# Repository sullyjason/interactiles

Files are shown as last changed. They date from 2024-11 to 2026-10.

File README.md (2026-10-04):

# Interactiles

[Portfolio Link](https://showspace.so/p/9350)

## Idea

Developing an interactive grid of buttons that light up and change colors when pressed, designed to communicate, connect, and create art across distances. Each grid is connected via the internet to a corresponding grid, allowing users to share visual messages in real-time.

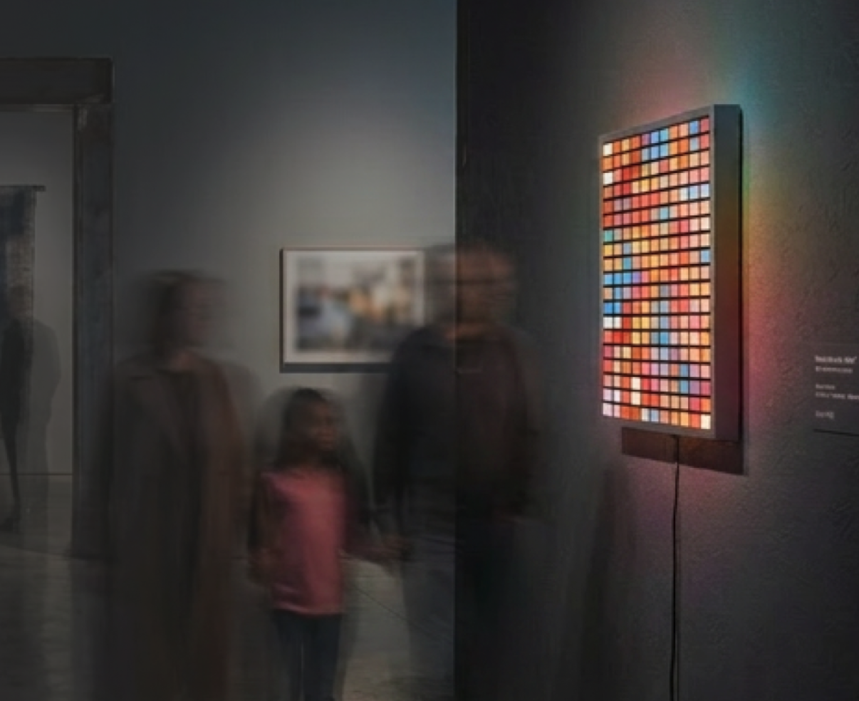
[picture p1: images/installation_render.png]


## Prototyping

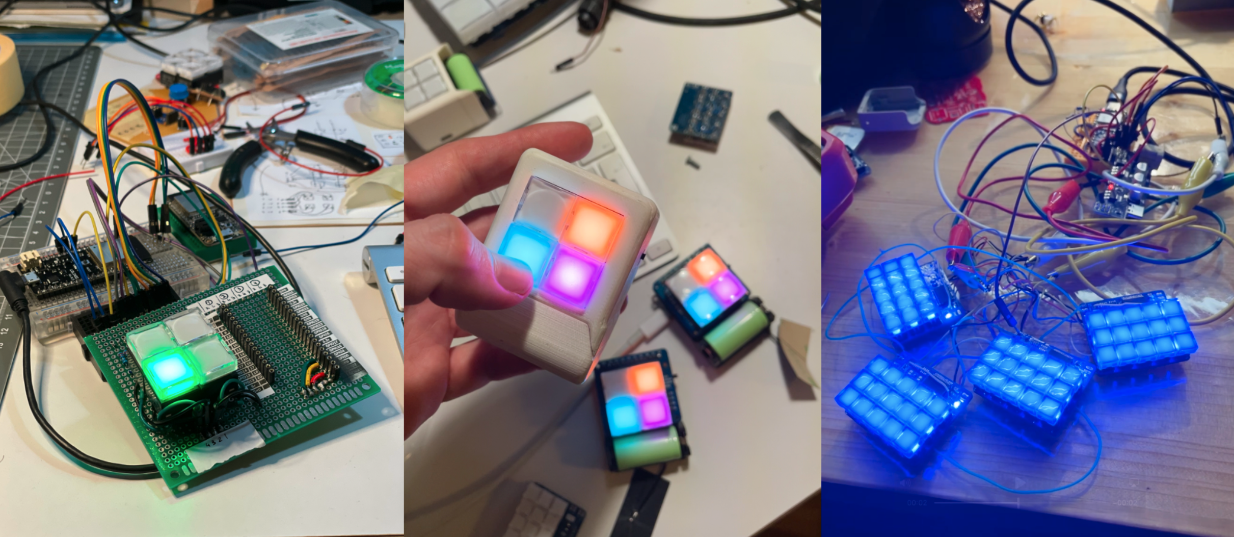
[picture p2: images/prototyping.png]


Until now, this project has served mostly as a platform for me to build on my coding and hardware skills. 

The current working prototype is a version with a 2x2 grid of RGB LED switches, connected to each other via an MQTT server.

The vision, of course, is a larger scale grid of clickable illuminated buttons. I am developing this with a modular approach, 4 tiles of 3x15 buttons controlled by a microcontroller that connects to the internet.

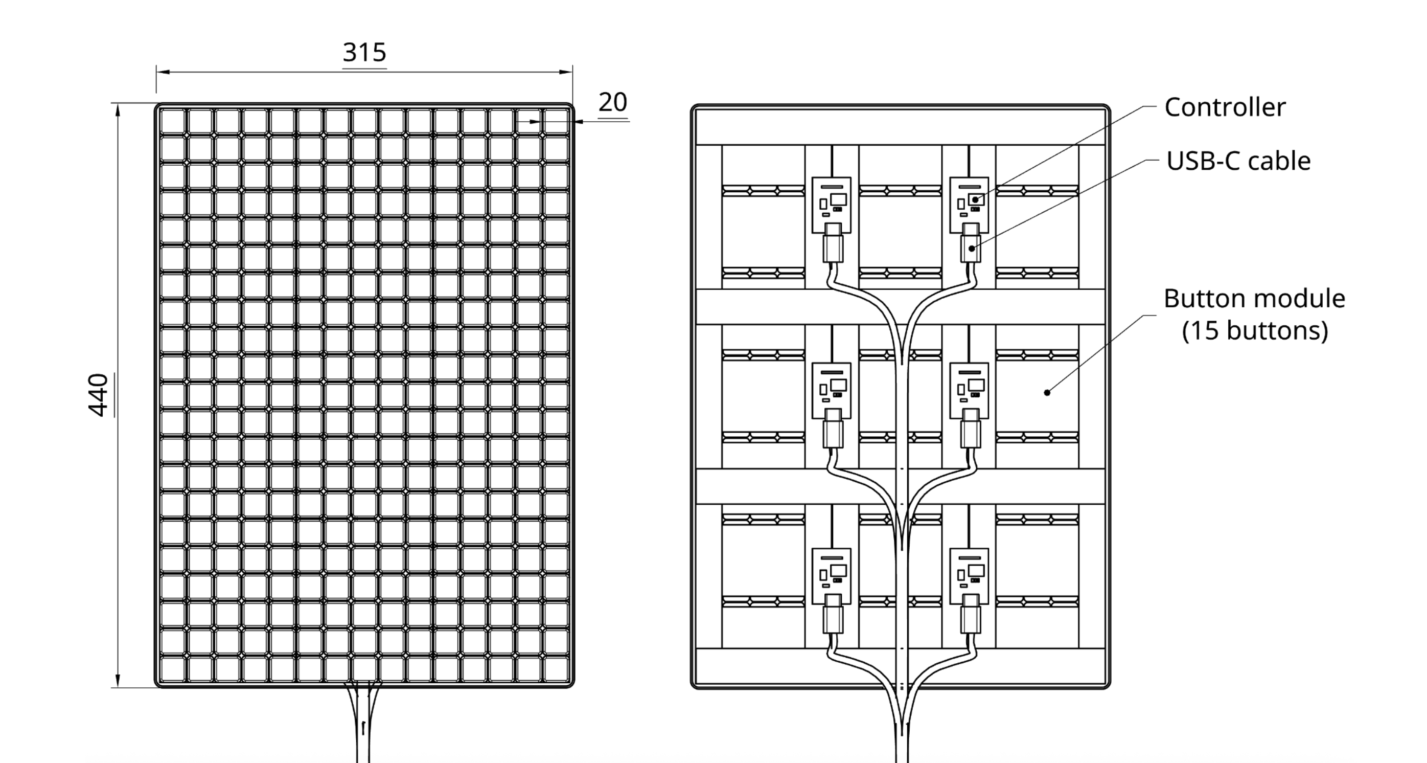
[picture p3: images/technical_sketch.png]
 

## To Do
- [x] Experiment with RGB Switches
- [x] Build hand-wired POC
- [x] Design PCB for 2x2 version
- [x] Assemble & test 2x2 version
- [x] Set up web server
- [x] Connect individual interactiles to web server
- [x] Web interface for monitoring
- [x] Large scale version module development (wip)
- [ ] Develop large scale version
- [ ] Design large scale modules
- [ ] Troubleshoot large scale modules
- [ ] Design miniature modules
- [ ] Enclosure for miniature modules
- [ ] Real world testing of 2x2 (in progress)

## Events

Exhibitions and real-world showings of Interactiles, each documented in its own folder under [`events/`](events/).

- [Zürich Decompression 2026](events/2026-decompression-zurich/) — two connected 5×3 grids in a fine-dining-inspired frame. Kraftwerk, Zürich, 9–11 October 2026.

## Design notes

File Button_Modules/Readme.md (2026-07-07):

# Button Modules

Addressable RGB switch panels in various sizes, built around 3×5 grids of NeoPixel-compatible switches. Button state is read via MCP23017 I2C I/O expanders. Switches are sourced from Lakeview Electronics in Shenzhen.

---

## Large Module

3×5 grid of PLB switches (~3×3 cm each). 15 switches routed to an FPC connector, with headers for the LED data line and screw terminals for 5V/GND.

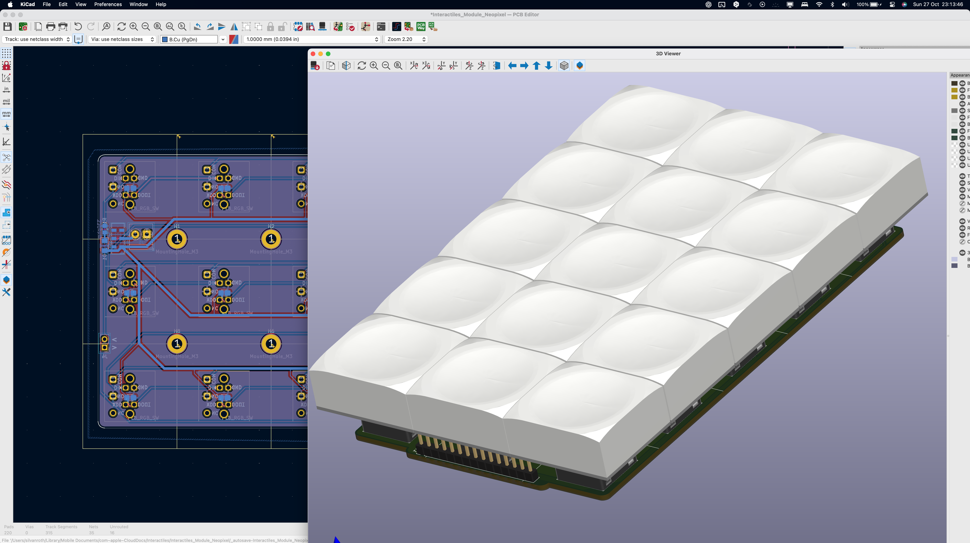
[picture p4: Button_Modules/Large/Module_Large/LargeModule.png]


→ [Large Module](Large/Module_Large/)

---

## Large Module I/O Expander

MCP23017-based expander board for the Large Module. Connects via FPC connector and reduces 15 switch lines to two I2C lines. I2C address set via DIP switch.

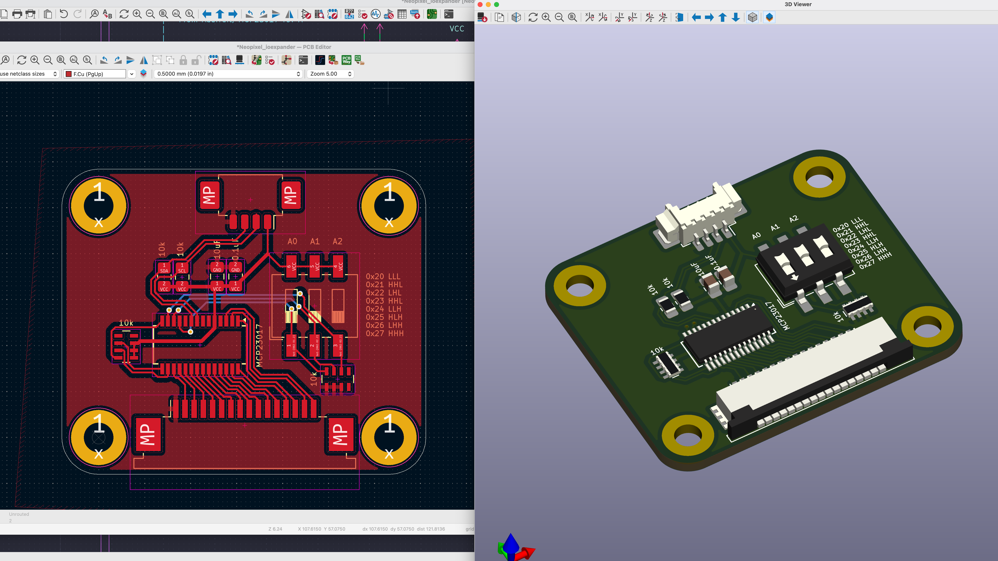
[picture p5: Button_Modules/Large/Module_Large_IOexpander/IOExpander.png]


→ [Module Large IOexpander](Large/Module_Large_IOexpander/)

---

## Mini Module

3×5 grid of TL1 switches (7.5mm² each). 4-layer board with MCP23017 mounted directly on the underside. Pinout is non-obvious due to space constraints — refer to schematic.

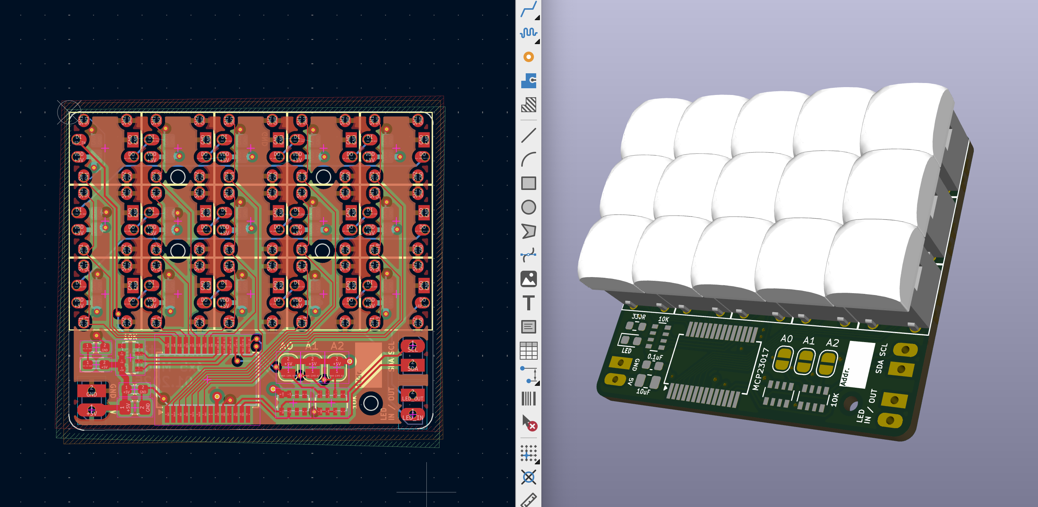
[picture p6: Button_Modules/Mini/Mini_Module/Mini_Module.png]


→ [Mini Module](Mini/Mini_Module/)

---

## Controllers

### 4x Mini Controller

Wireless ESP32 controller for up to 4 Mini Modules (60 pixels). Connects via I2C to MCP23017 expanders, drives one NeoPixel data line. Uses Li-ion batteries with BMS, battery charger etc.

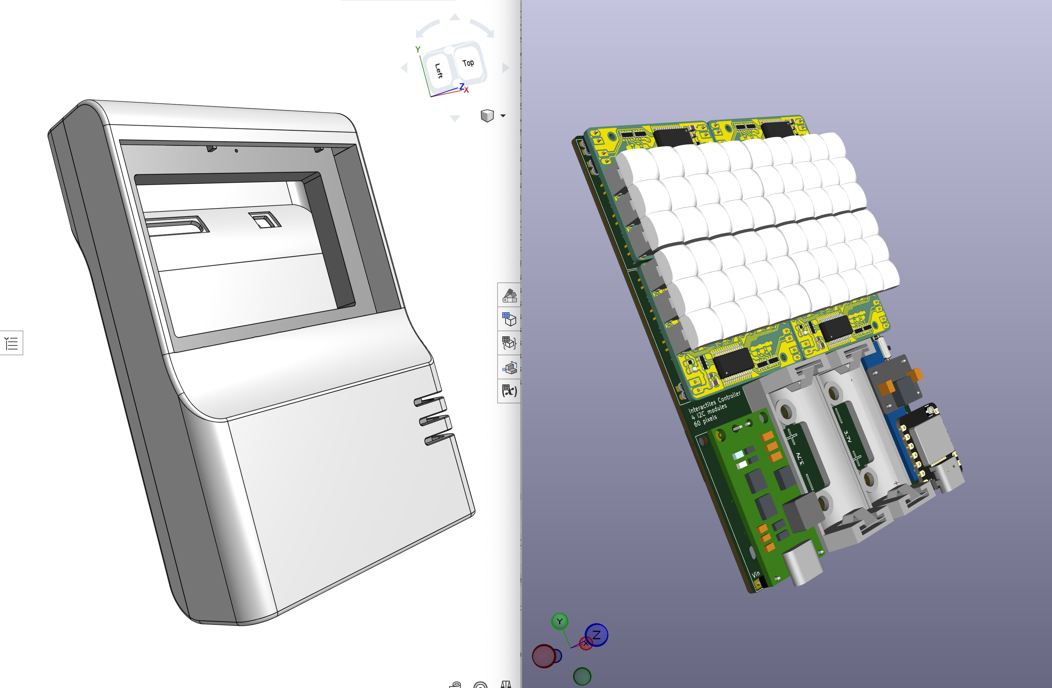
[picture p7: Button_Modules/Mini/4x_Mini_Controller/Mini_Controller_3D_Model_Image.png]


→ [4x Mini Controller](Mini/4x_Mini_Controller/)

### 4x Mini Controller Wired

Wired variant of the 4x Mini Controller, no batteries

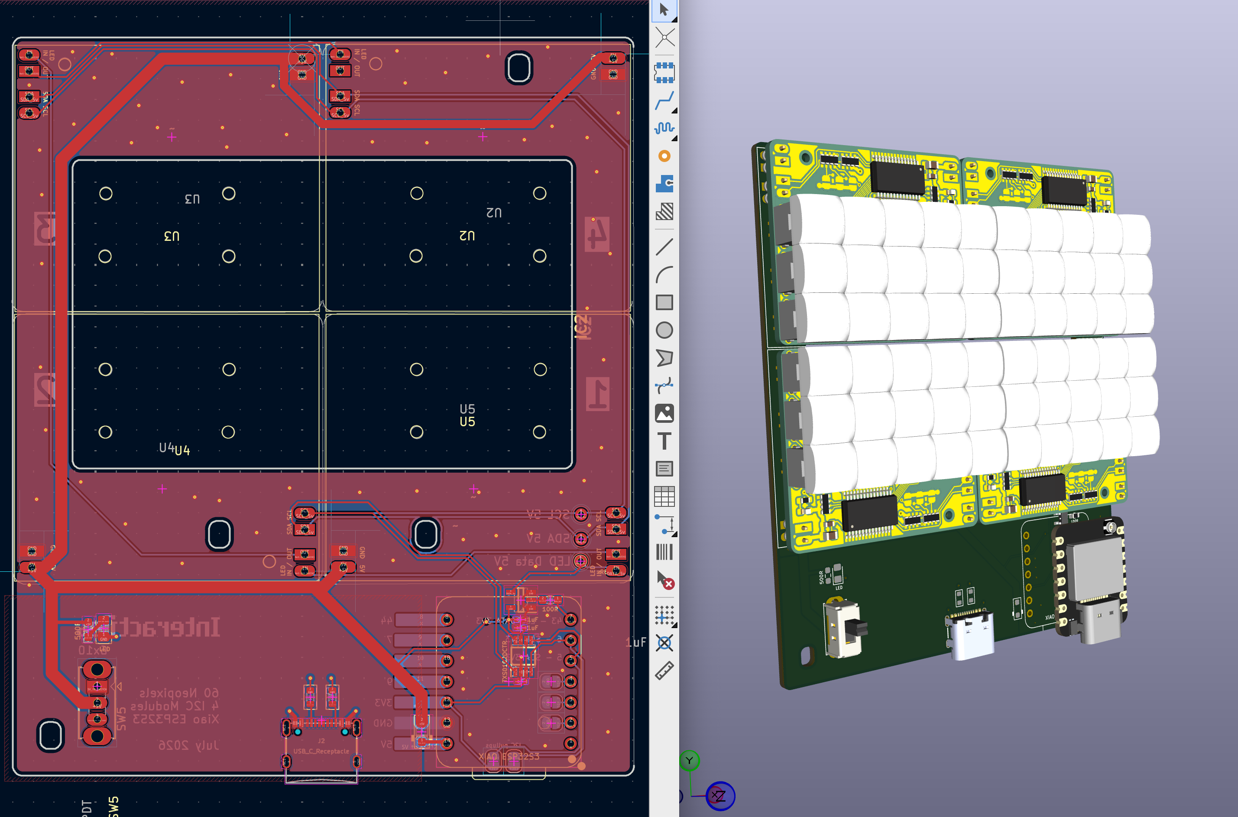
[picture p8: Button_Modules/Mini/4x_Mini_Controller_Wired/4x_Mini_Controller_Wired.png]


→ [4x Mini Controller Wired](Mini/4x_Mini_Controller_Wired/)

### Solo Mini Controller

Standalone controller for a single 3×5 Mini Module.

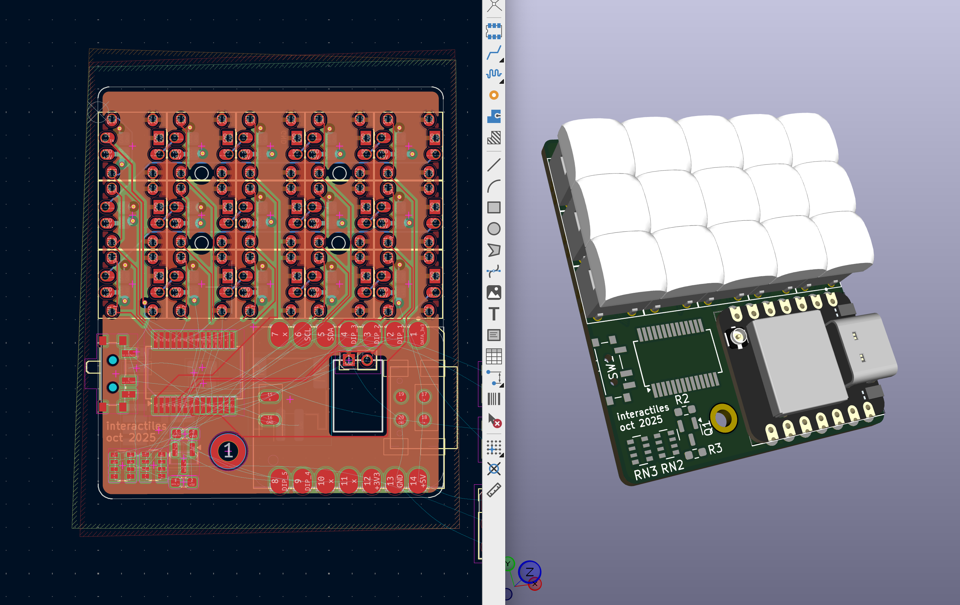
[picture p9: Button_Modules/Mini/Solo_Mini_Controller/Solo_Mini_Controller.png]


→ [Solo Mini Controller](Mini/Solo_Mini_Controller/)

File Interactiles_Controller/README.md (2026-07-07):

# Interactiles Controller PCB

Main controller board for the scaled-up Interactiles installation.

## Board

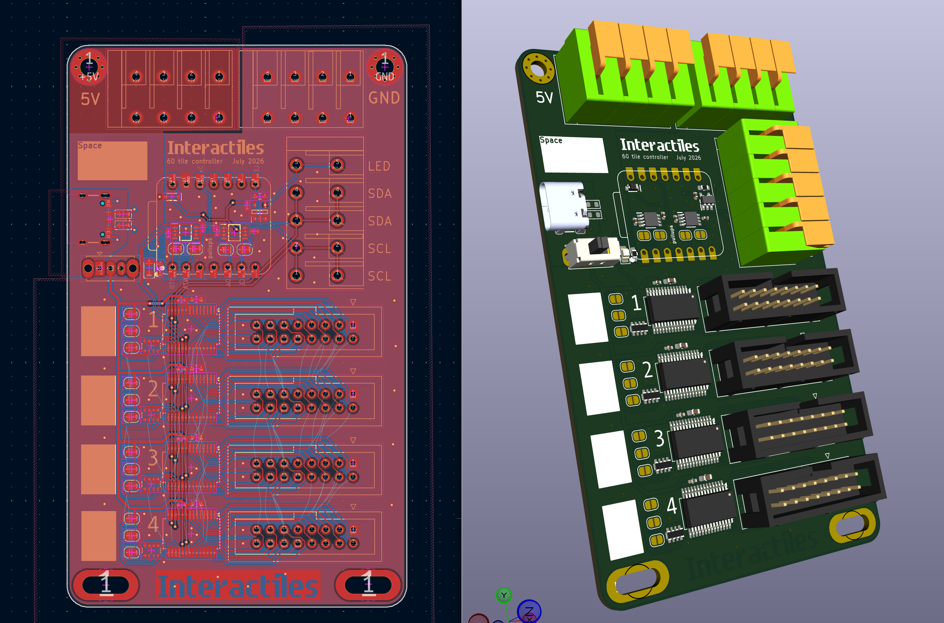
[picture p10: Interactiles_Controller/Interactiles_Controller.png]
Board


## Bodges

<!-- Document any wire fixes or component swaps here, with photos -->

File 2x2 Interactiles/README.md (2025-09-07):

readme.md

# 2x2 Interactile

Device with a 2x2 matrix of RGB Switches, controlled by an ESP32. The switches are arranged in a matrix configuration. WS2811 IC's control the RGB LEDs embedded in the switches, controlled using the Adafruit Neopixel library. 

The enclosure is 3D printed in PLA with an acrylic backplate, secured with M2 screws and a knurled nut to allow for easy battery switching. 

The battery is a CR123 sized 3.7 Li-Ion and provides the entire device with power. A polarity protection circuit protects the PCB but there is no charging circuit. 

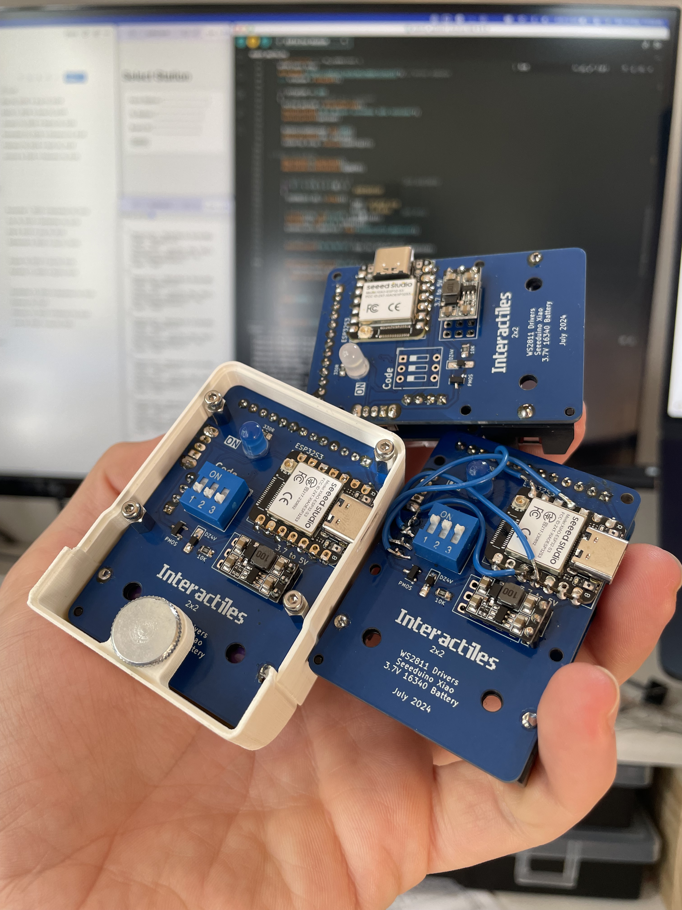
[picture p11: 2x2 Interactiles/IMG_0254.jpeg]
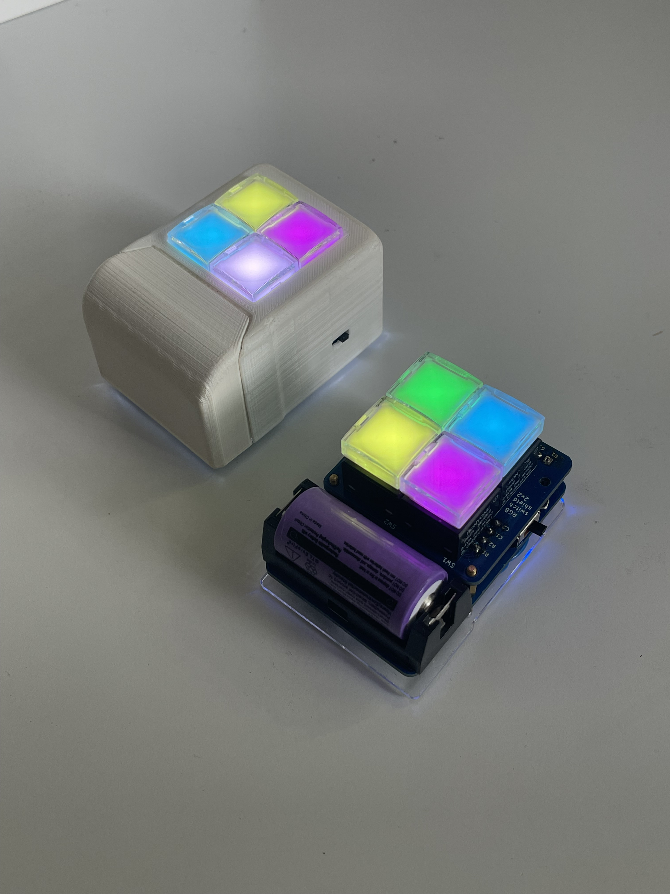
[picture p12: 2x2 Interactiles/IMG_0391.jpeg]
 

### Interfacing via MQTT

The current code in the folder named "MQTT" connects the interactiles to an MQTT server, where they publish and subscribe to channels that correspond to the individual pixels. 

The server is located at 
```c++
mqtt_server = "test.mosquitto.org";
mqtt_port = 1883;
base_topic = "interactiles/space1";
```

Configure Wifi settings here
```C++
// Wi-Fi credentials
const char* ssid = "SSID";
const char* password = "PASSWORD";
```

The channel structure is as follows:
interactiles/space[]/row/col/r,g,b

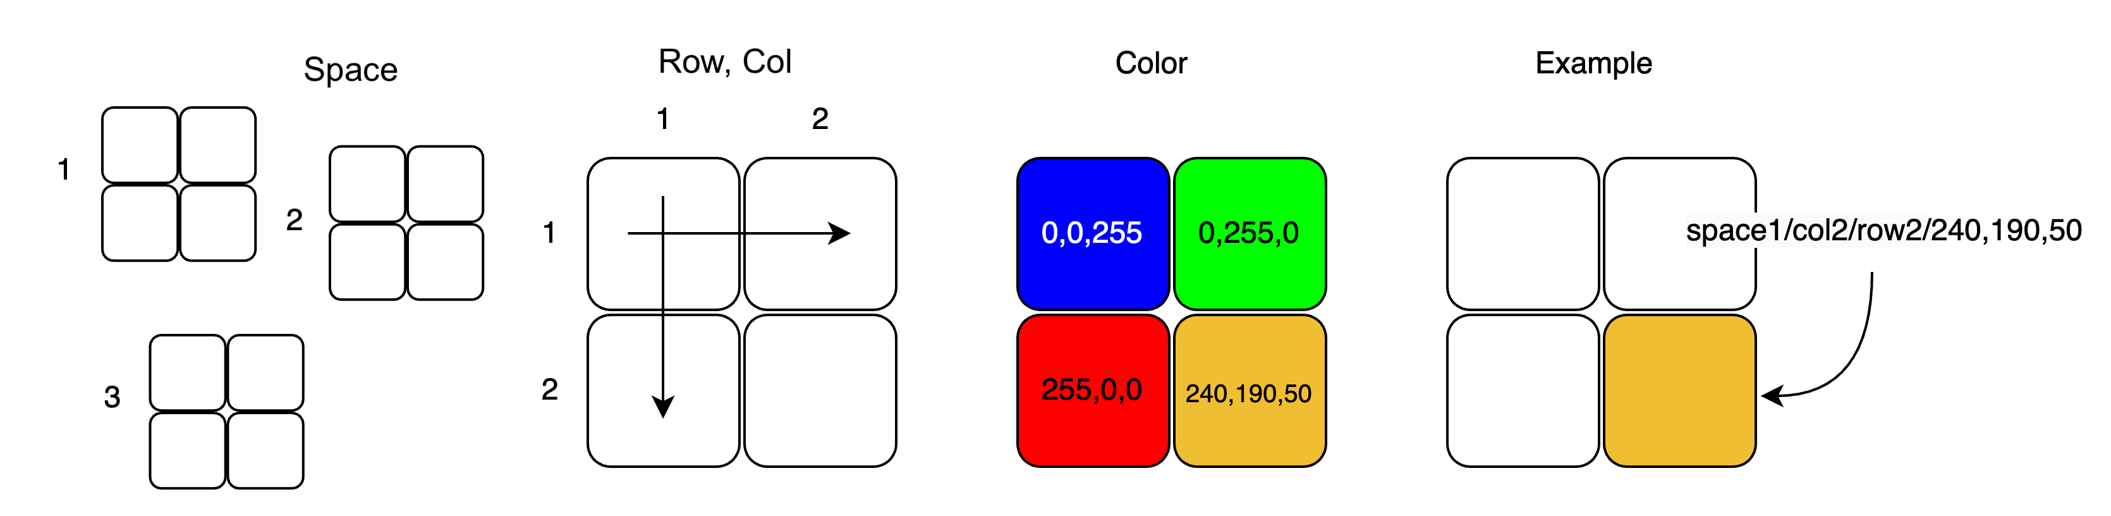
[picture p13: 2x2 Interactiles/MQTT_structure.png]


The space ID is currently hardcoded. In future versions it should be possible to set this via a DIP switch or similar.

row and column are matched to a specific RGB Switch as follows:
```c++
int mapToLedIndex(int row, int col) {
  if (row == 1 && col == 1) return 0;
  if (row == 1 && col == 2) return 2;
  if (row == 2 && col == 1) return 1;
  if (row == 2 && col == 2) return 3;
  return -1;
}
```

## Future changes
 
- Current version uses WS2811 LED drivers. Replace with intelligent RGB LED Switches
- Improve power management: Use xiao ESP32S3's onboard charging or redesign charging circuit. Alternatively, completely elminate wireless option
- Fix dip switch behavior
- Spaces architecture: The idea of spaces is that multiple devices can exist in the same space and be a part of the same image. Idea for naming: space1.1, space 1.2, etc.
- Hardcode meta data on each device and have the devices respond to each other accordingly
- MQTT or wifi connecting animation for improved usability
- consider creating a docking station
- Add wifi manager library

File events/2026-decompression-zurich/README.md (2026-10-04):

# Zürich Decompression 2026

**Status:** Upcoming — installation planned for 9–11 October 2026.

## The event

[Zürich Decompression 2026](https://zurich-decompression.web.app/) is a Burning Man decompression — a community gathering where burners process the burn through art, performances and workshops. It is volunteer-run, organised by the Zürich burner community, and held at **Kraftwerk, Zürich**.

This year's theme is *The Grand Hotel for Peculiar Burners*, where participants check in with a declared peculiarity that frames their experience. The guiding principle is that **the Hotel is built by whoever turns up** — everything is participant-created rather than organiser-programmed, and there are no spectators at a burn.

Art is submitted through the event's *Grand Hotel Dreams* category, with funding available for materials and transport.

| | |
|---|---|
| **Dates** | 9–11 October 2026 (Fri build night · Sat main event · Sun strike) |
| **Venue** | Kraftwerk, Zürich |
| **Website** | https://zurich-decompression.web.app/ |

## Our proposal

Submitted by **Silvan & Marco** to the Zürich Decompression art grant, September 2026.

The original Interactiles vision is a large-scale grid of several hundred illuminated buttons. For this event we proposed a **deliberately scaled-down version that stays close to the original concept**:

- **Two interactive 5×3 LED grids** — 15 physical buttons/LEDs per block, rather than the ~300 of the full concept.
- The two grids **communicate with each other**, preserving the core idea of connection across distance.
- To compensate for the small pixel count, the work leans on **presentation**: each grid is set in a generous, carefully built frame — in Marco's words, the way tiny portions of the best food are placed on giant plates at a fine dining restaurant.

This is a slight conceptual shift from the full installation, trading raw scale for framing and craft.

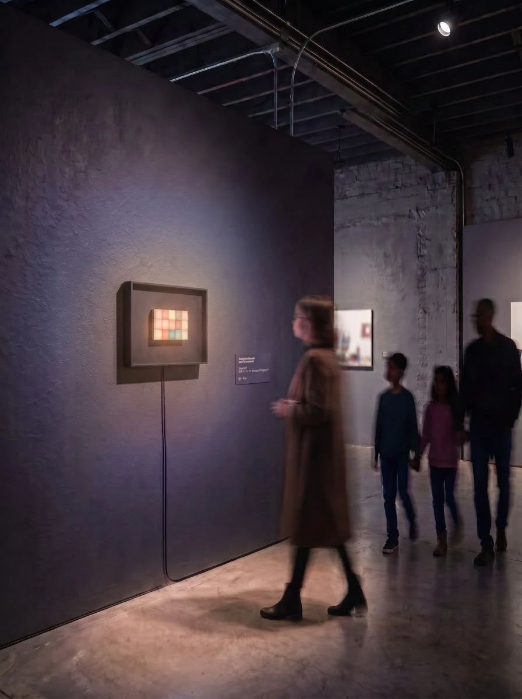
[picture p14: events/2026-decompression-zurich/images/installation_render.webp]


### Why this scope

The decisive factor was feasibility within the available timeframe. Marco got the **existing prototype working without significant hardware changes**, which meant the scaled-down version needs no complex component orders with long and risky delivery times. Effort goes into the two things that actually determine whether it works on the night:

1. A **sturdy frame**.
2. **Reliable software**.

Budget: **approximately CHF 500**, covering materials and transport.

### What we want out of it

A chance to test the concept in a **real event setting** and see how people actually interact with it. If it works, we plan to develop the larger installation together for next year's Decompression — with more time to build properly and significantly lower risk overall.

## What we're building

Both halves of the piece are built from boards that already exist in this repo — this is the point of the scaled-down scope, and the reason no new fabrication orders were needed.

### Boards

| Part | Board | Source |
|---|---|---|
| Brain | **Interactiles Controller** | [`Interactiles_Controller/`](../../Interactiles_Controller/) |
| Buttons | **2 × Large Module** | [`Button_Modules/Large/Module_Large/`](../../Button_Modules/Large/Module_Large/) |

**Controller** — built around a **XIAO ESP32-S3** for wifi and the MQTT link between the two grids. Button reads go through **4 × MCP23017** I²C port expanders (64 inputs available, of which this build uses 30), with TXS0102 level shifters on the I²C lines and an SN74AHCT1G125 buffer to lift the LED data line to 5 V. Modules connect over 2×16 IDC headers, with lever terminals for power distribution.

**Large Module** — a 3×5 grid of **PLB-N1PRGB-GTW-AI** illuminated RGB switches (15 per board, ~3×3 cm each), routed out to an FPC connector, with a header for LED data and a screw terminal for 5 V/GND.

Two modules give the **two 5×3 grids** of the proposal: 30 buttons total.

### Power

The controller is powered over **USB-C**, via a **5 m cable** into a **100 W charging brick**. Expected draw is **no more than ~15 W** — the load is dominated by the 30 RGB switches, and the controller itself is negligible beside them. The oversized brick is deliberate: the extra capacity is there for when the installation scales, not for this build.

### Open risks

- **LED data signal loss** on the Large Module is a known, still-unresolved issue (noted in that board's own README). Since reliable software and a working piece on the night are the whole point of this scope, this is the main technical risk to close before the event.
- **Power headroom is not currently accessible.** The controller's USB-C port is a plain 5 V sink — two 5.1 kΩ CC pulldowns, with no PD negotiation IC on the BOM — so it will only ever pull 5 V from the brick, capping it at roughly 15 W no matter how large the supply is. That is fine for this build, but the 100 W will not become available at scale without either a PD trigger/sink IC and a buck stage, or a separate 5 V supply.
- **5 m at 5 V is a long run.** Voltage drop across the cable scales with current, so a thin cable may brown the LEDs out at full brightness even though the brick is oversized. Worth using a cable with heavy (20 AWG or better) power conductors, and worth testing at full white before the event.

## Retrospective

*To be filled in after the event: what we built, what worked, what broke, how people interacted with it, and what we would change for the full-scale version.*

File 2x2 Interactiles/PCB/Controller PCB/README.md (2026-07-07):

# 2x2 Controller PCB

ESP32-based controller board for the 2x2 Interactile. Drives 4 WS2811 NeoPixels and reads a 2x2 keypad matrix.

## Schematic

<!-- Paste schematic screenshot here -->

## Board

<!-- Paste board layout screenshot here -->

## Bodges

<!-- Document any wire fixes or component swaps here, with photos -->

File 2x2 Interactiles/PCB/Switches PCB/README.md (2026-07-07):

# 2x2 Switches PCB

Breakout board for the Honyone RGB switches in the 2x2 Interactile. Routes switch contacts and WS2811 LED data lines to a connector.

## Schematic

<!-- Paste schematic screenshot here -->

## Board

<!-- Paste board layout screenshot here -->

## Bodges

<!-- Document any wire fixes or component swaps here, with photos -->

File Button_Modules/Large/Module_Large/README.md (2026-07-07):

# Large Module PCB

3×5 grid of PLB NeoPixel switches (~3×3 cm each). 15 switches routed to an FPC connector, with headers for LED data and screw terminals for 5V/GND.

## Board

Board

## Bodges

WIP - signal loss issues on LED Data line.

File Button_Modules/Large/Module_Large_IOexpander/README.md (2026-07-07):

# Module Large I/O Expander PCB

MCP23017-based I/O expander module. Reduces 15 individual switch lines to two I2C lines. I2C address set via DIP switch. Compatible with the Large Module via FPC connector.

## Schematic

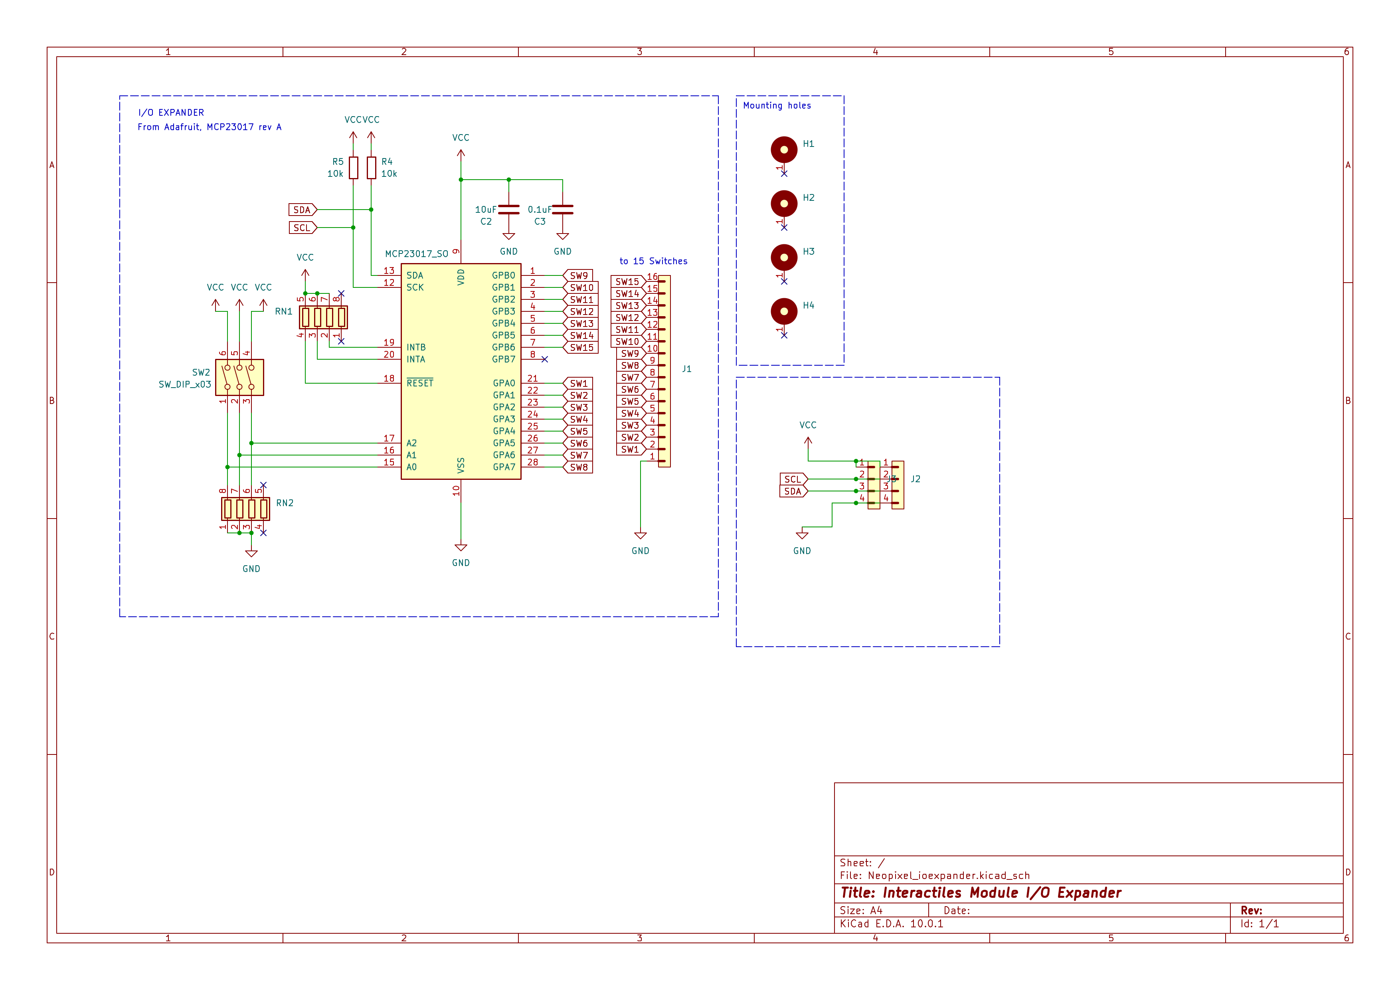
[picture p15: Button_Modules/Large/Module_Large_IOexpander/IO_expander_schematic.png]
Schematic


## Board

Board

## Bodges

i2c pullups are redundant if using several of these expanders, interrupt pins are tied high and not available for use

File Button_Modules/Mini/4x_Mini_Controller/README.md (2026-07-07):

# 4x Mini Controller PCB

ESP32 controller for a string of up to 8 3×5 NeoPixel modules. Interfaces: I2C (for MCP23017 expanders), NeoPixel data line, common ground. Includes USB-C and optional battery charging.

## Schematic

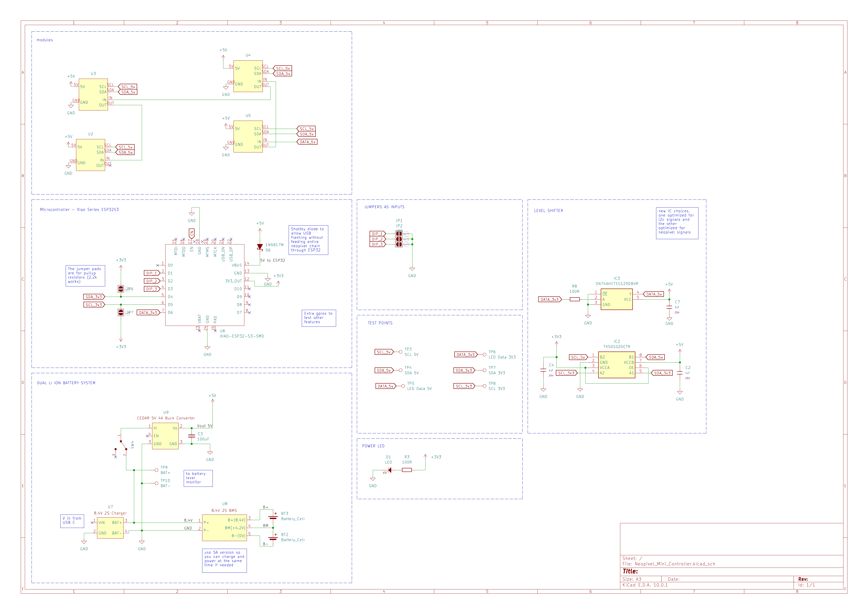
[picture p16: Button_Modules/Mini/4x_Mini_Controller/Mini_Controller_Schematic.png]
Schematic


## Board

Board

## Bodges

<!-- Document any wire fixes or component swaps here, with photos -->

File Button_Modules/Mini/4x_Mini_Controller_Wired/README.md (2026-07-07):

# 4x Mini Controller Wired PCB

Wired controller variant for a 4× 3×5 Mini Module Interactiles installation.

## Board

Board

## Bodges

<!-- Document any wire fixes or component swaps here, with photos -->

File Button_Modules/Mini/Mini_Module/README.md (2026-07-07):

# Mini Module PCB

3×5 grid of TL1 NeoPixel switches (7.5mm² each). 4-layer board with MCP23017 I/O expander mounted directly on the underside. Pinout is non-obvious due to space constraints — refer to schematic.

## Board

Board

## Bodges

<!-- Document any wire fixes or component swaps here, with photos -->

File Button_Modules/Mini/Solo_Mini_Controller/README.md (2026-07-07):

# Solo Mini Controller PCB

Standalone controller for a single 3×5 Mini Module.

## Board

Board

## Bodges

<!-- Document any wire fixes or component swaps here, with photos -->

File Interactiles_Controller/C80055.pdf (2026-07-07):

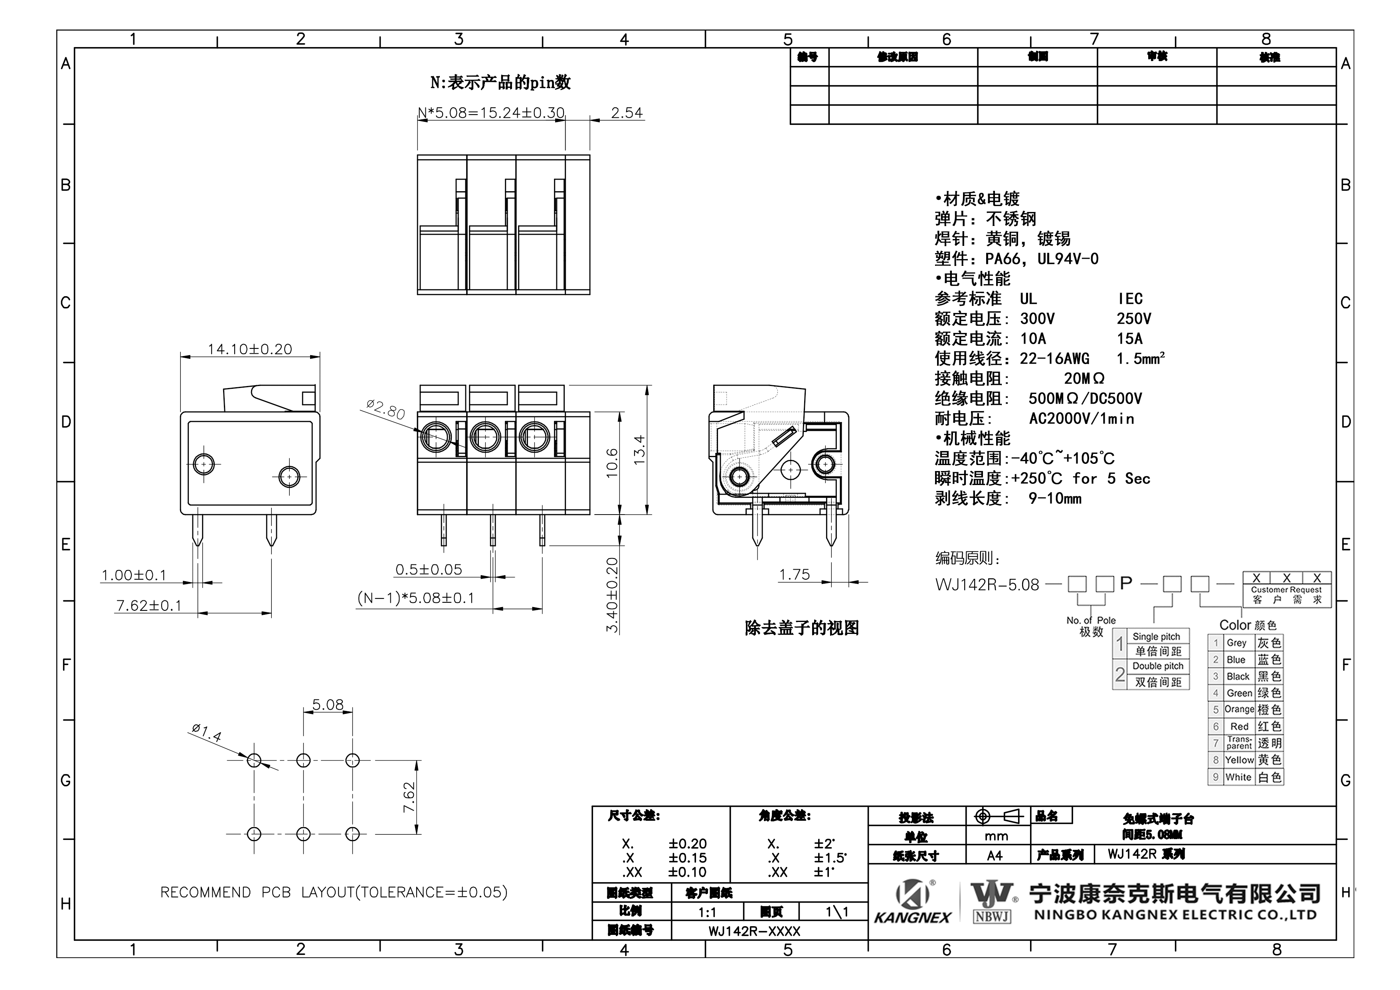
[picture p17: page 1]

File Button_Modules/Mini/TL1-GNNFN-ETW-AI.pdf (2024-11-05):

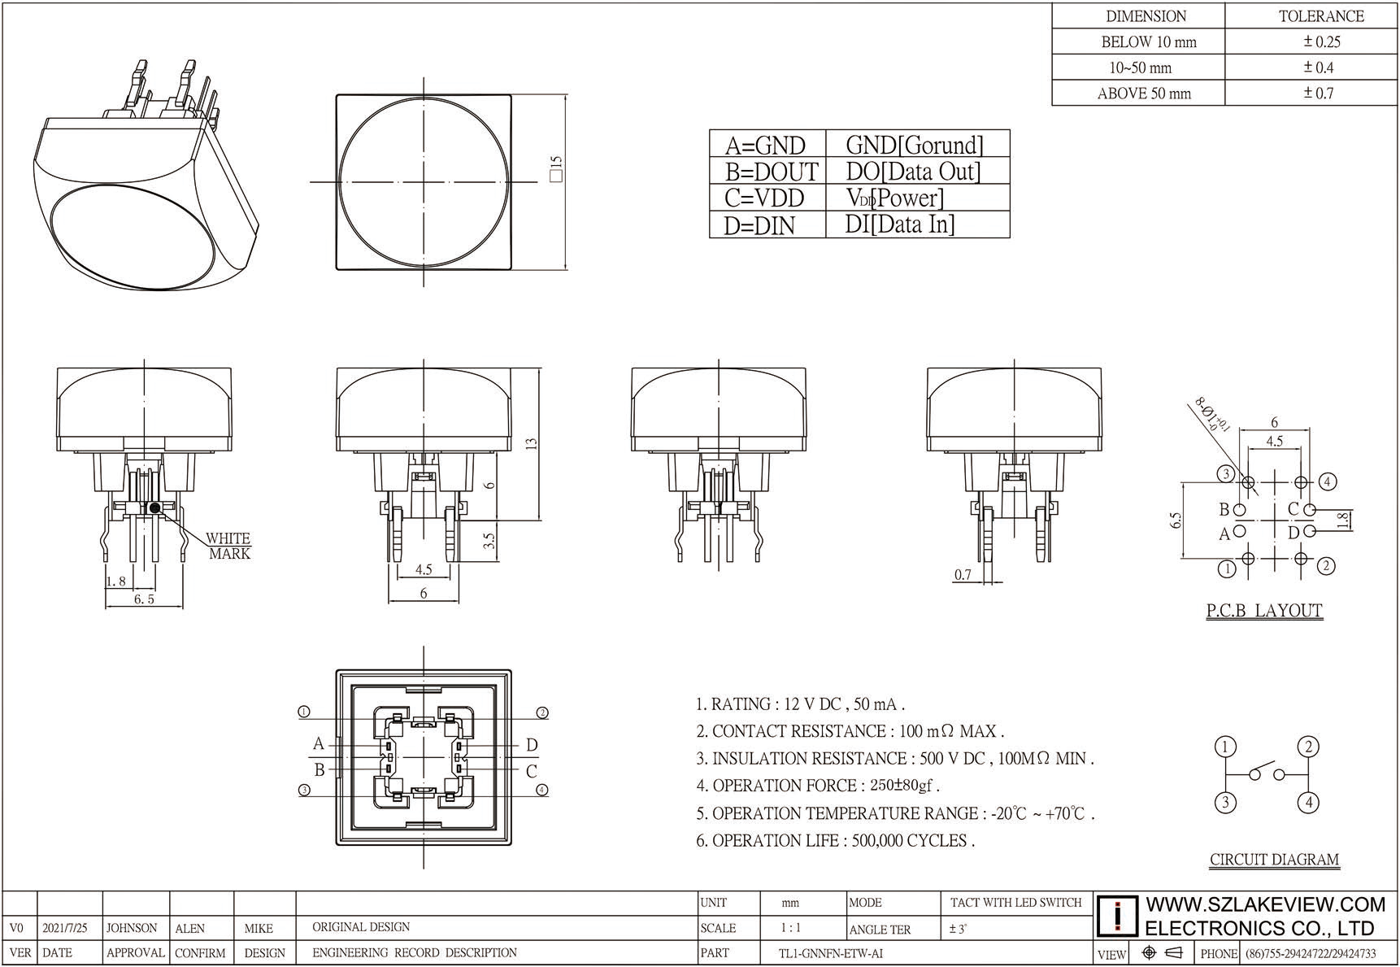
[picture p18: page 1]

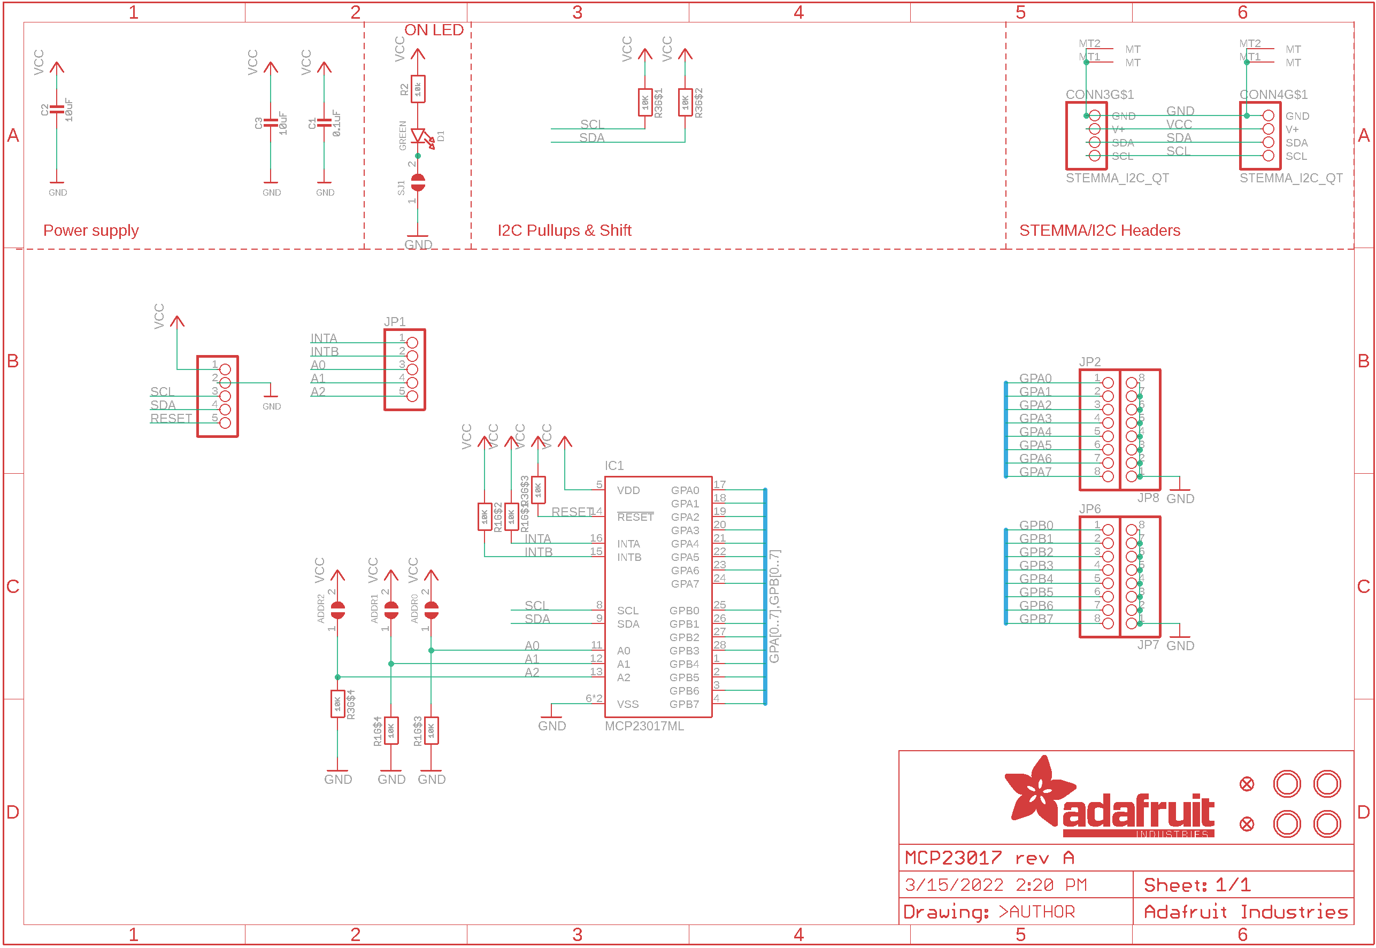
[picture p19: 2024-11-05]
Button_Modules/Components/Adafruit MCP23017 Schematic.png

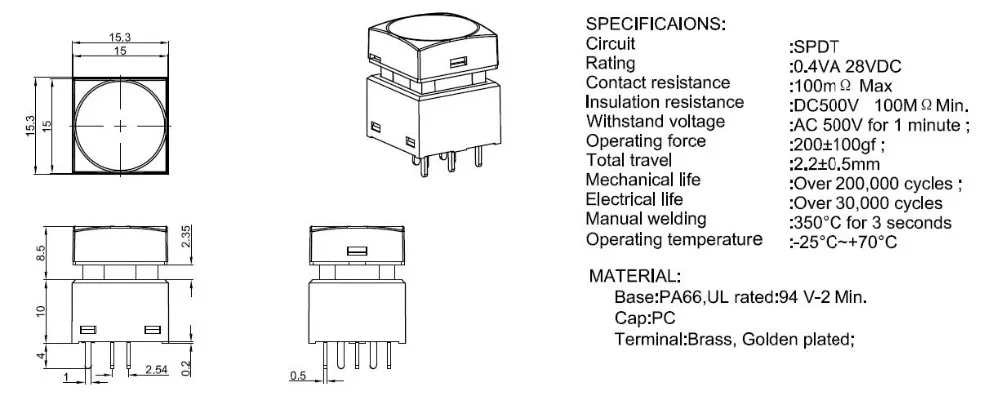
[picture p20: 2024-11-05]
2x2 Interactiles/PB26.jpg

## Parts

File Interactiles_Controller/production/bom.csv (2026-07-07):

Designator | Footprint | Quantity | Value | LCSC Part #
C2, C4, C6, C7, C8 | C_0402 | 5 | 1uF | C52923
C3_4, C3_3, C3_2, C3 | 0603 | 4 | 10uF
C5_4, C5_3, C5_2, C5 | 0402 | 4 | 0.1uF
D1 | 0805 | 1 | LED
D6 | SOD-323 | 1 | BAT60J
IC2, IC4 | TXS0102DCTR | 2 | TXS0102DCTR
IC3 | SN74AHCT1G125DBVR | 1 | SN74AHCT1G125DBVR
J2 | USB-C_16 | 1 | USB_C_Receptacle
J3, J4 | Lever_Terminal_1x04_WJ142R-5.08 | 2 | Screw_Terminal_01x04
J5 | Lever_Terminal_1x05_WJ142R-5.08 | 1 | Screw_Terminal_01x05
J7_4, J7_3, J7_2, J7 | IDC-Header_2x08_P2.54mm_Vertical | 4 | Conn_01x16
R1, R2 | 0603 | 2 | 5.1k
R3, R8 | 0603 | 2 | 100R
RN1_4, RN1_3, RN1_2, RN1 | R_Array_Convex_4x0603 | 4 | 10k
SW4 | SW_Slide_SPDT_Straight_CK_OS102011MS2Q | 1 | Slide_Switch_SPDT
U2_4, U2_3, U2_2, U2 | SSOP-28_5.3x10.2mm_P0.65mm | 4 | MCP23017_SS
U6 | XIAO-ESP32-S3-DIP | 1 | XIAO-ESP32-S3-SMD

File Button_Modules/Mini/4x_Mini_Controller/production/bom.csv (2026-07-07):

Designator | Footprint | Quantity | Value | LCSC Part #
BT2, BT3 | BHC-CR123A | 2 | Battery_Cell
C2, C4, C7 | C_0402 | 3 | 1uF | C52923
C3 | 1206 | 1 | 100uF
D1 | 0805 | 1 | LED
D6 | D_SOD-323_BigPads | 1 | 1N5817M
IC2 | TXS0102DCTR | 1 | TXS0102DCTR
IC3 | SN74AHCT1G125DBVR | 1 | SN74.
R3, R8 | 0603 | 2 | 100R
SW4 | SW_SPDT_PCM12 | 1 | Slide_Switch_SPDT
TP10 | TestPoint_THTPad_D1.5mm_Drill0.7mm | 1 | BAT-
TP3 | TestPoint_THTPad_D1.5mm_Drill0.7mm | 1 | SCL 5V
TP4 | TestPoint_THTPad_D1.5mm_Drill0.7mm | 1 | SDA 5V
TP5 | TestPoint_THTPad_D1.5mm_Drill0.7mm | 1 | LED Data 5V
TP9 | TestPoint_THTPad_D1.5mm_Drill0.7mm | 1 | BAT+
U2, U3, U4, U5 | Mini_Module | 4 | ~
U6 | XIAO-ESP32-S3-DIP | 1 | XIAO-ESP32-S3-SMD
U7 | 2S_Li_Ion_Charger | 1 | 8.4V 2S Charger
U8 | 8.4V_2S_BMS | 1 | 8.4V 2S BMS
U9 | CEDAR_5V_4A_Buck_Converter | 1 | 5V 4A Stepdown

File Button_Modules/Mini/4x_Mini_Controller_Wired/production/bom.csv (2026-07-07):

Designator | Footprint | Quantity | Value | LCSC Part #
C2, C4, C7 | C_0402 | 3 | 1uF | C52923
D1 | 0805 | 1 | LED
D6 | D_SOD-323_BigPads | 1 | 1N5817M
IC2 | TXS0102DCTR | 1 | TXS0102DCTR
IC3 | SN74AHCT1G125DBVR | 1 | SN74AHCT1G125DBVR
J2 | USB-C_16 | 1 | USB_C_Receptacle
R1, R2 | 0603 | 2 | 5.1k
R3 | 0603 | 1 | 500R
R8 | 0603 | 1 | 100R
SW5 | SW_Slide_SPDT_Straight_CK_OS102011MS2Q | 1 | Slide_Switch_SPDT
TP3 | TestPoint_THTPad_D1.5mm_Drill0.7mm | 1 | SCL 5V
TP4 | TestPoint_THTPad_D1.5mm_Drill0.7mm | 1 | SDA 5V
TP5 | TestPoint_THTPad_D1.5mm_Drill0.7mm | 1 | LED Data 5V
U2, U3, U4, U5 | Mini_Module | 4 | ~
U6 | XIAO-ESP32-S3-DIP | 1 | XIAO-ESP32-S3-SMD

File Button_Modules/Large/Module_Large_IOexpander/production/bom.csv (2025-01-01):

Designator | Footprint | Quantity | Value | LCSC Part #
0.1uF | 0805 | 1 | 0.1uF
10k_4, 10k_3 | R_Array_Concave_4x0603 | 2 | R_Pack04
10k_2, 10k | 0805 | 2 | 10k
10uF | 0805 | 1 | 10uF
H1, H2, H3, H4 | MountingHole_3.2mm_Pad | 4 | MountingHole_M3_3.2mm_Pad
J1 | TE_1-84952-6_1x16-1MP_P1.0mm_Horizontal | 1 | PINHD_1x16_Male
J2 | Molex_PicoBlade_53261-0471_1x04-1MP_P1.25mm_Horizontal | 1 | PINHD_1x4_Male
J3 | PinHeader_1x04_P2.54mm_Vertical | 1 | PINHD_1x4_Male
MCP23017 | SOIC-28W_7.5x17.9mm_P1.27mm | 1 | MCP23017_SO
SW2 | SW_DIP_SPSTx03_Slide_6.7x9.18mm_W8.61mm_P2.54mm_LowProfile | 1 | SW_DIP_x03

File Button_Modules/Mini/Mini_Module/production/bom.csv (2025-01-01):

Designator | Footprint | Quantity | Value | LCSC Part #
0.1uF | 0603 | 1 | 0.1uF
10uF | 0805 | 1 | 10uF
J1 | PinHeader_1x02_P2.00mm_Vertical | 1 | PINHD_1x2_Male
J2, J4 | PinHeader_1x02_P2.00mm_Vertical | 2 | PINHD_1x2_Female
LED | 0603 | 1 | LED
MCP23017 | SSOP-28_5.3x10.2mm_P0.65mm | 1 | MCP23017_SS
R1 | 0603 | 1 | 330R
RGB_SW1, RGB_SW10, RGB_SW11, RGB_SW12, RGB_SW13, RGB_SW14, RGB_SW15, RGB_SW2, RGB_SW3, RGB_SW4, RGB_SW5, RGB_SW6, RGB_SW7, RGB_SW8, RGB_SW9 | TL1_RBG_Adressable_1_mini | 15 | PLB_RGB_SW
RN1, RN2, RN3 | R_Array_Convex_4x0603 | 3 | R_Pack04

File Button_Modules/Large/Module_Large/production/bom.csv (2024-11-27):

Designator | Footprint | Quantity | Value | LCSC Part #
D1 | 1206 | 1 | LED
J1 | TerminalBlock_Phoenix_PT-1,5-2-3.5-H_1x02_P3.50mm_Horizontal | 1 | Screw_Terminal_2_P3.50mm
J2 | PinHeader_1x15_P2.54mm_Vertical | 1 | PINHD_1x15_Male
J3 | TE_1-84952-6_1x16-1MP_P1.0mm_Horizontal | 1 | PINHD_1x15_Male
J4 | PinSocket_1x02_P2.54mm_Vertical | 1 | PINHD_1x2_Female
R1 | 0805 | 1 | 330ohm
RGB_SW1, RGB_SW10, RGB_SW11, RGB_SW12, RGB_SW13, RGB_SW14, RGB_SW15, RGB_SW2, RGB_SW3, RGB_SW4, RGB_SW5, RGB_SW6, RGB_SW7, RGB_SW8, RGB_SW9 | PLB-N1PRGB-GTW-AI | 15 | PLB_RGB_SW
SW1 | SW_DPDT_CK_JS202011JCQN | 1 | SW_SPST

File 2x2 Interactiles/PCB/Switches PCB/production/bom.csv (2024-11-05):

Designator | Footprint | Quantity | Value | LCSC Part #
J1 | PinHeader_1x04_P2.54mm_Vertical | 1 | PINHD_1x4_Male
J2 | PinHeader_1x13_P2.54mm_Vertical | 1 | PINHD_1x13_Male
SW1 | Honyone Tactile Switch RGB | 1 | RGB_SW_1
SW2 | Honyone Tactile Switch RGB | 1 | RGB_SW_2
SW3 | Honyone Tactile Switch RGB | 1 | RGB_SW_3
SW4 | Honyone Tactile Switch RGB | 1 | RGB_SW_4

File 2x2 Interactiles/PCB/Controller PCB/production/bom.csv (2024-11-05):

Designator | Footprint | Quantity | Value | LCSC Part #
3.7V | BHC-CR123A | 1 | Battery 3.7V
C1, C2, C3, C4 | 0805 | 4 | 100nF_Ceramic
D1 | LED_D3.0mm | 1 | LED_3mm
D2 | 0805 | 1 | DZ4V
J1 | PinSocket_1x04_P2.54mm_Vertical | 1 | Switches
J2 | PinSocket_1x13_P2.54mm_Vertical | 1 | LEDs
J5 | PinSocket_1x03_P2.54mm_Vertical | 1 | 3.7 to 5V
PMOS | SOT-23 | 1 | AO3401A
R1, R6, R7, R8 | 0805 | 4 | 100R
R11 | 0805 | 1 | 330R
R2, R3, R4 | 0805 | 3 | 33R
R5, R9 | 0805 | 2 | 10k
SW1 | SW_Slide_SPDT_Angled_CK_OS102011MA1Q | 1 | SW_SPST
SW2 | SW_DIP_SPSTx03_Slide_9.78x9.8mm_W7.62mm_P2.54mm | 1 | SW_DIP_x03
U1 | Seeeduino XIAO-MOUDLE14P-2.54-21X17.8MM | 1 | SeeeduinoXIAO
U2, U3, U4, U5 | HSOP-8-1EP_3.9x4.9mm_P1.27mm_EP2.3x2.3mm | 4 | WS2811

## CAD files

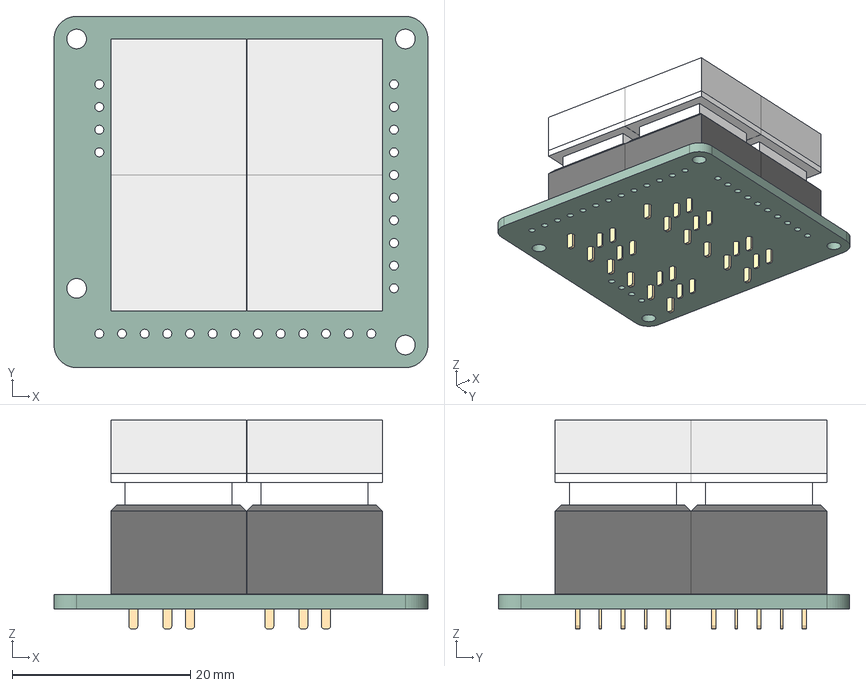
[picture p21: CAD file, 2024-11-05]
2x2 Interactiles/Enclosure/Honyone RGB Shield.step
41.9 x 39.4 x 23.4 mm
11ABBC06-2790-4AA7-BFDE-7ACAB21791F7 x 4
_autosave-Honyone RGB Shield_PCB

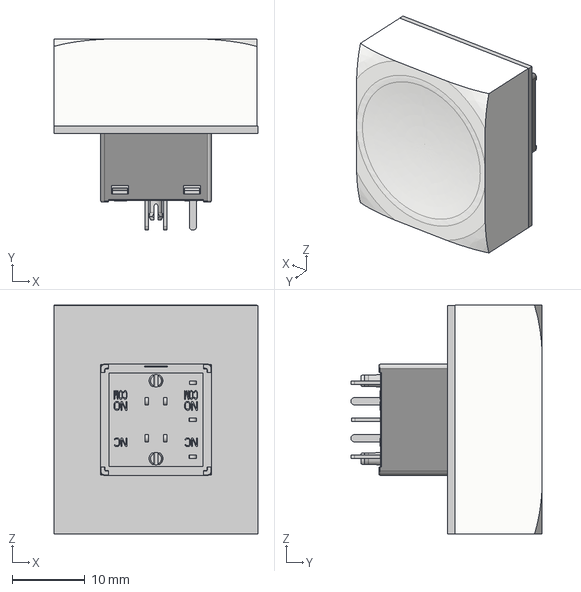
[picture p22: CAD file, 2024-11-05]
Button_Modules/Components/3D Files/PLB-N1PRGB-GTW-AI v2.step
28.0 x 26.3 x 31.5 mm

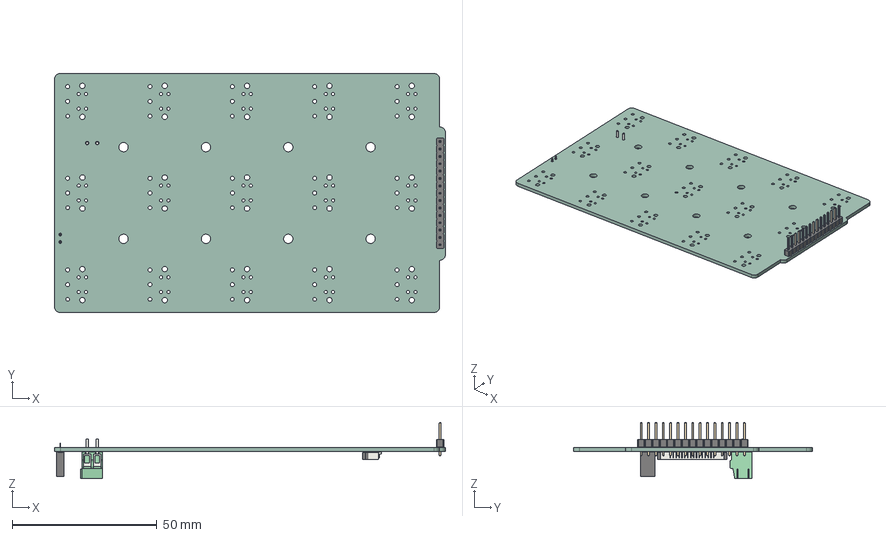
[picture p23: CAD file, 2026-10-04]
Button_Modules/Large/Module_Large/Neopixel_Mini_Controller_wired2.step
134.8 x 82.4 x 19.4 mm
PinHeader_1x15_P2.54mm_Vertical
PinSocket_1x02_P2.54mm_Vertical
R_0805_2012Metric
LED_1206_3216Metric
TerminalBlock_Phoenix_PT-1,5-2-3.5-H_1x02_P3.50mm_Horizontal
TE_1-84952-6_1x16-1MP_P1.0mm_Horizontal
Interactiles_Module_Neopixel_PCB

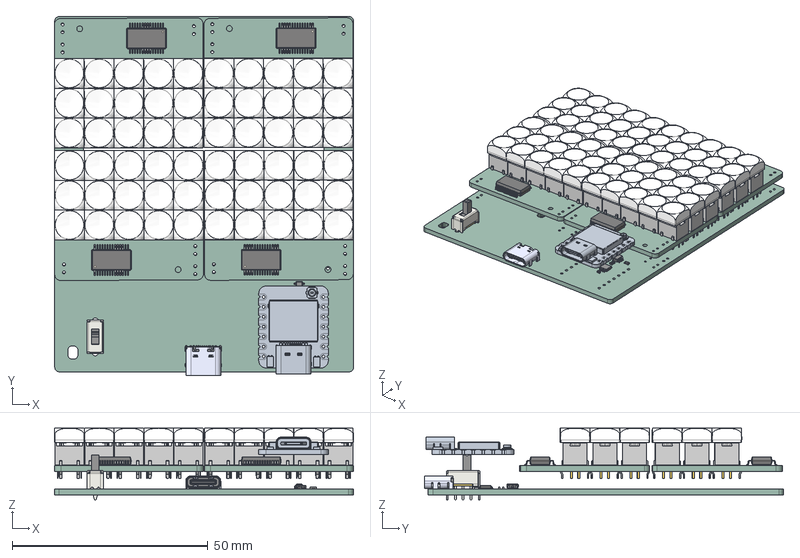
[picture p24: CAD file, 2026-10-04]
Button_Modules/Mini/4x_Mini_Controller_Wired/Neopixel_Mini_Controller_wired2.step
76.4 x 91.7 x 18.3 mm
C_0402 x 3
TL1-mini x 60
SSOP-28_5.3x10.2mm_P0.65mm x 4
Mini_Module_PCB x 4
BODY-SOT
LEAD-SOT x 5
LEAD-DUMMY
R_0603_1608Metric
BODY-SO
LEAD-SO x 8
PIN1-ID
Seeed_XIAO-ESP32S3
SW_Slide_SPDT_Straight_CK_OS102011MS2Q
USB4105GFA_USB4105GFA
4x_Mini_Controller_Wired_PCB

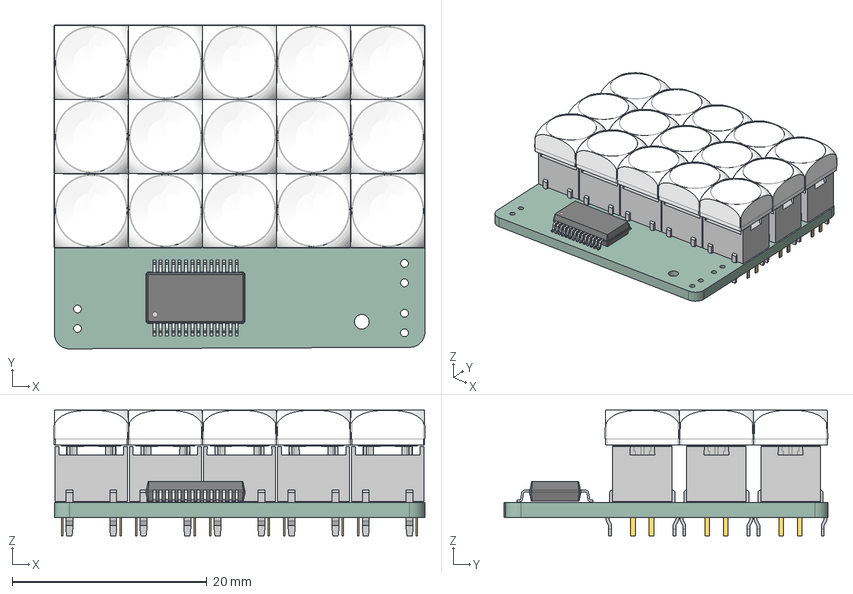
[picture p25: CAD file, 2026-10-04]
Button_Modules/Mini/Mini_Module/Neopixel_Mini_Controller.step
38.1 x 33.2 x 12.9 mm
TL1-mini x 15
SSOP-28_5.3x10.2mm_P0.65mm
Mini_Module_PCB

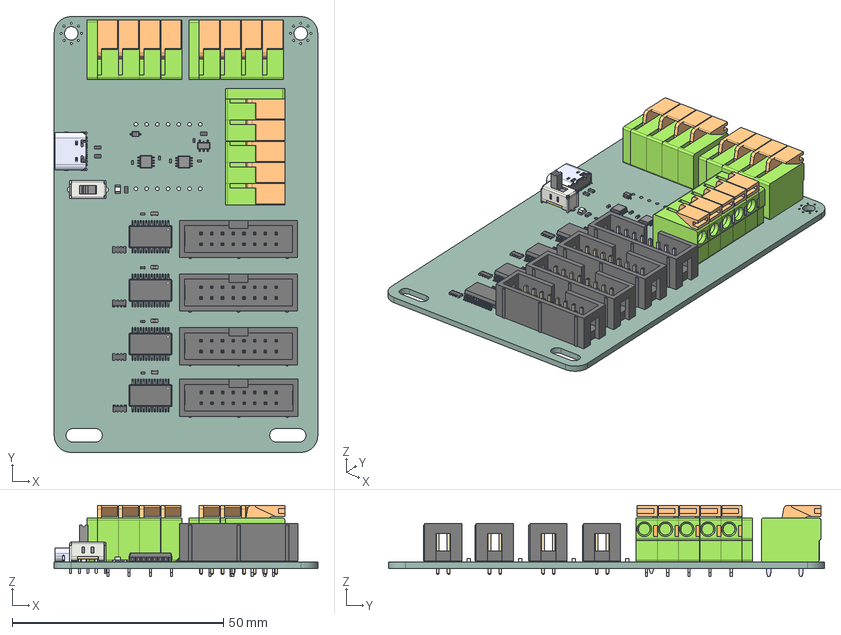
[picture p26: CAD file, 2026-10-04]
Interactiles_Controller/Interactiles_Controller.step
62.5 x 103.3 x 16.9 mm
C_0603_1608Metric x 4
R_Array_Convex_4x0603 x 4
R_0603_1608Metric x 4
C_0402 x 9
BODY-SO x 2
LEAD-SO x 16
PIN1-ID x 2
SW_Slide_SPDT_Straight_CK_OS102011MS2Q
LED_0805_2012Metric
SSOP-28_5.3x10.2mm_P0.65mm x 4
DG142R-2-5.08 x 16
D_SOD-323
BODY-SOT
LEAD-SOT x 5
LEAD-DUMMY
IDC-Header_2x08_P2.54mm_Vertical x 4
USB4105GFA_USB4105GFA
Interactiles_Controller_PCB

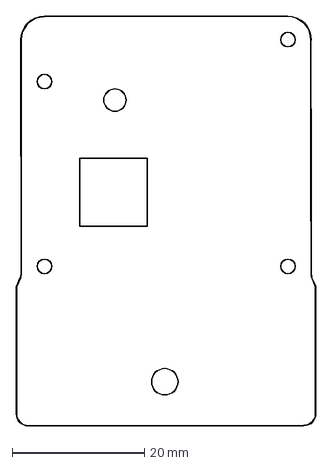
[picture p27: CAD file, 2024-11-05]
2x2 Interactiles/Enclosure/Backplate.dxf
45.3 x 62.0 mm

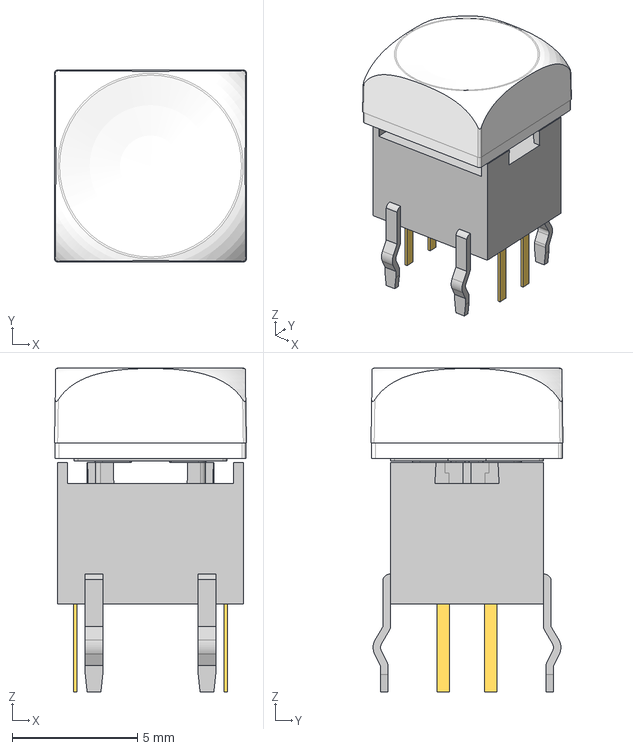
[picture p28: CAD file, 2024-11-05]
Button_Modules/Components/3D Files/TL1-mini.step
7.65 x 7.65 x 12.9 mm

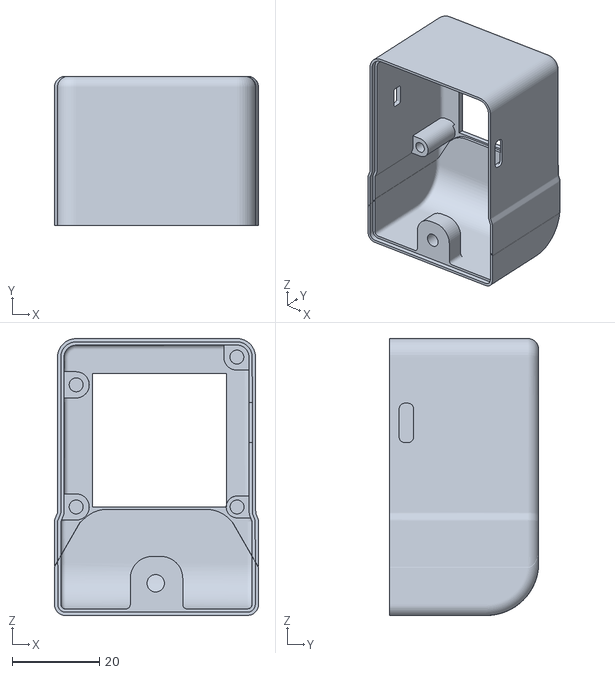
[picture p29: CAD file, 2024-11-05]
Interactiles/2x2 Interactiles/Enclosure/Enclosure.stl
46.7 x 34.2 x 63.4

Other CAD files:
2x2 Interactiles/PCB/Switches PCB/Honyone RGB Shield.step
Interactiles/2x2 Interactiles/PCB/Switches PCB/Honyone RGB Shield.step

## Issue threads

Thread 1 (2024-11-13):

Review

besi, 2024-11-13:
Hy there I did a quick review of your PCB ;-)
Front:
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

Back:
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

Schematic

- [ ] What are the Resistor values (not shown in the schematic)
- [ ] Use a defacto-standard  4 Pin I2C footprint (StemmaQT and QWIIC are compatible):
   - [ ] [Stemma](https://www.youtube.com/watch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) / [QWIIC](https://www.sparkfun.com/qwiic) I2C connector (JLC# [C160390](https://jlcpcb.com/partdetail/Jst-BM04B_SRSS_TB_LF_SN/C160390)) and/or
    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

   - [ ] 0.254mm Headers (GND, 3V, DATA, CLK)
   - [ ] [Adaptor](https://www.digikey.ch/de/products/detail/sparkfun-electronics/DEV-14495/7942483) from Header to two QWIICs

PCB / Mechanical

- [ ] Add a github link
- [ ] M3 holes: Mounting holes are always good to place and they are built right into kicad: SCHEMATIC: `Mechanical:MountingHole` PCB: `MountingHole:MountingHole_3.2mm_M3`
- [ ] Rounded corners are a plus and it looks a bit more professional
- [ ] 10k Resistors on the back could be in another Resistor array
- [ ] The three connectors on the back are facing towards the solder joints of the buttons it might be hard to connect the connector when there are solder joints in the way. Maybe rotate them or move them to further to the edge.
- [ ] Add a 3d model of your buttons
- [ ] Make it dummy-proof to mount the buttons
   - [ ] Do they go to the front or the back (I assume the front)
   - [ ] `RGB_SW1` should probably be moved/copied to the back because on a four layer board it's not visible how the buttons are ordered (left-right / up-down)
- [ ] It's a good practise to assume that the person soldering your PCB won't have the Schematic file. What information will they (or your future self) need that's not yet shown on the PCB
- [ ] A logo would be nice :-)
- [ ] I like to add the Git commit along with a date and a version number
    Because suddenly you may have three versions that look very similar and a lot of changes in Git
    So I would have a generic commit label on my PCB in Silkscreen: `Commit: 0xaabbcc`, now I do all the changes before sending the PCB to the FAB and commit them which gives me the SHA. I now take 6 hex digits from that sha, add it to the final PCB so `Commit: 0x76de40` and send it to the FAB. And now I reject that last change so the Silkscreen goes back to the generic placeholder commit.
- [ ] The solder joints at the top edge look quite close to the edge (almost like [castellated holes](https://jlcpcb.com/blog/castellated-pcbs-introduction-and-design-requirements)

Some Ideas / Remarks

- [ ] Maybe have the MCPP23017
- [ ] Possibly add an optional 16th neopixel for debugging or as a status LED on the side?
- [ ] I wonder, could this be done as a two layer board

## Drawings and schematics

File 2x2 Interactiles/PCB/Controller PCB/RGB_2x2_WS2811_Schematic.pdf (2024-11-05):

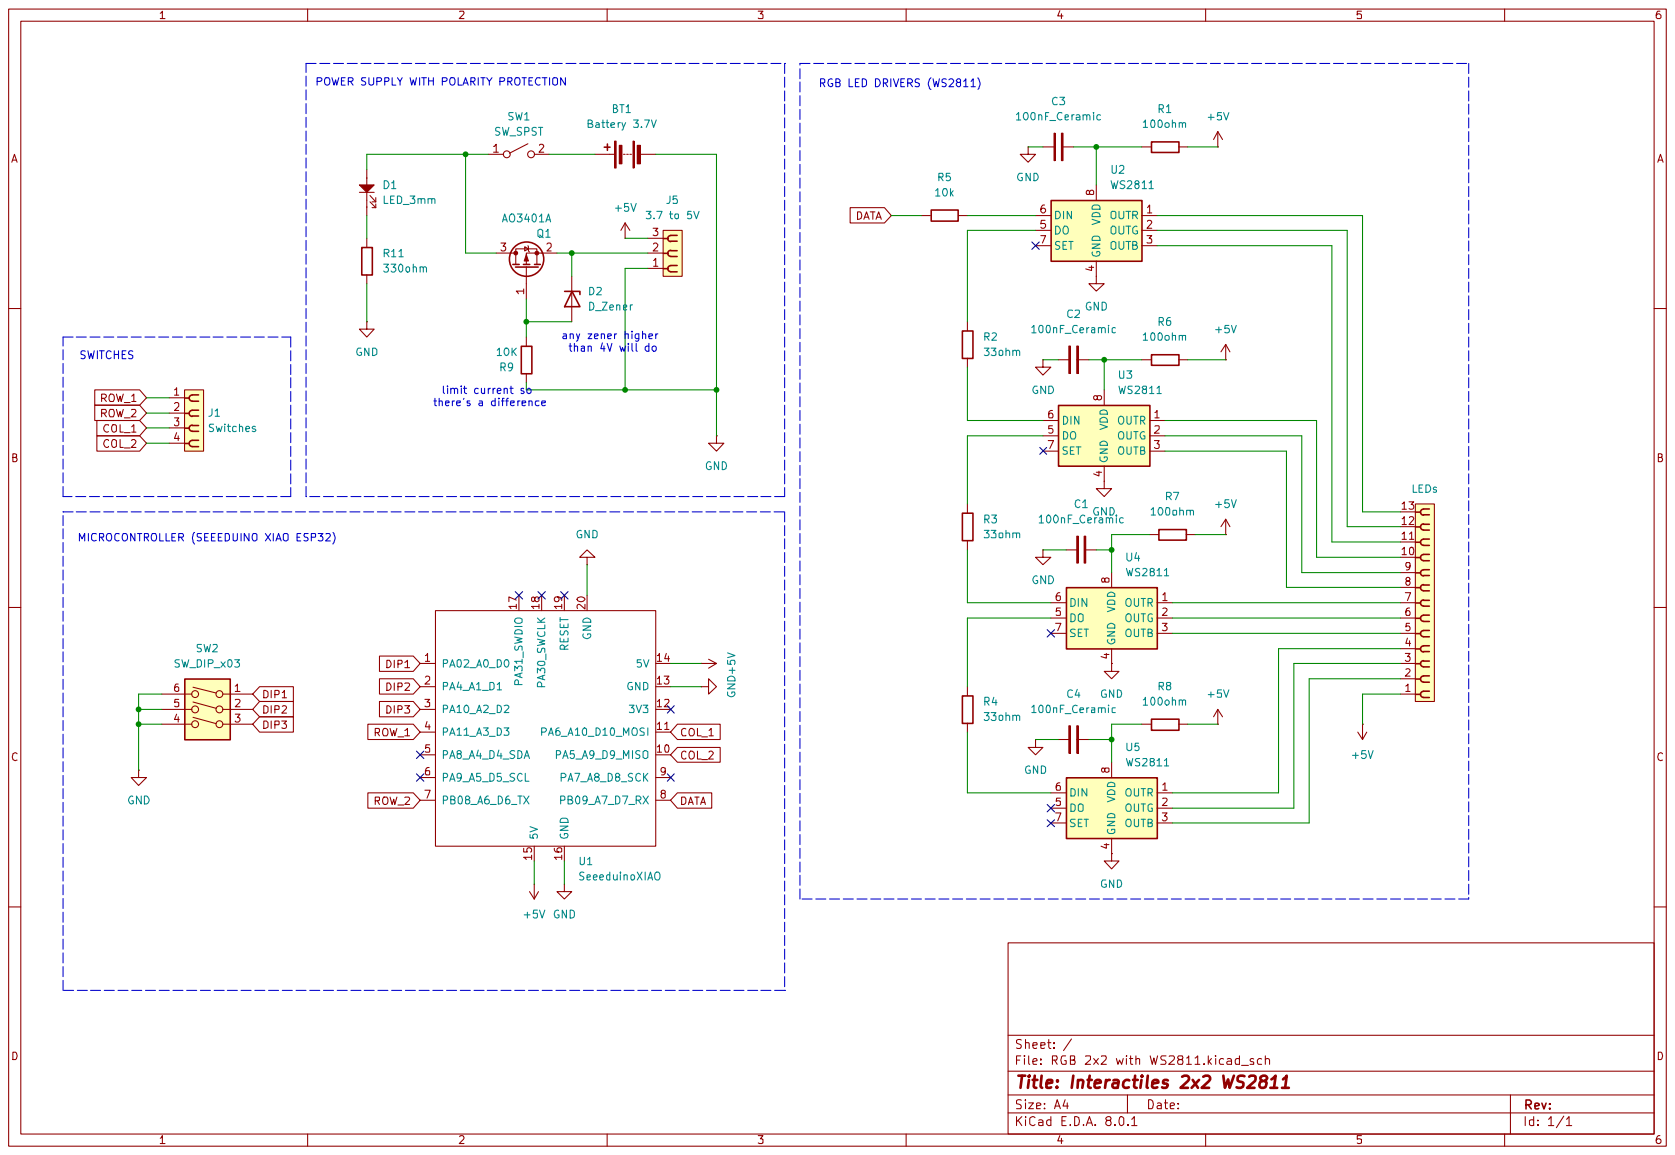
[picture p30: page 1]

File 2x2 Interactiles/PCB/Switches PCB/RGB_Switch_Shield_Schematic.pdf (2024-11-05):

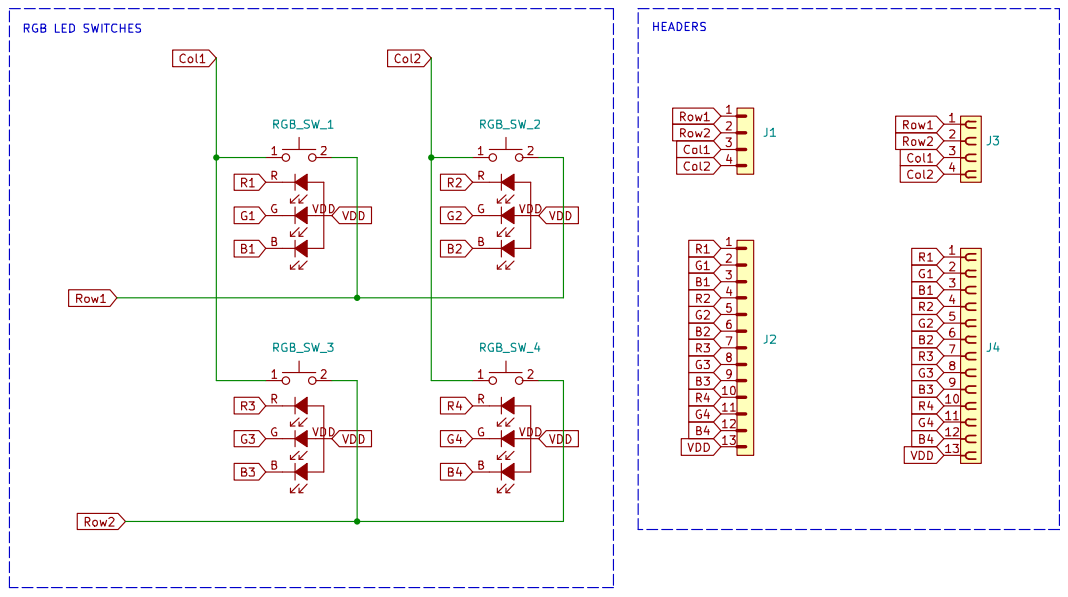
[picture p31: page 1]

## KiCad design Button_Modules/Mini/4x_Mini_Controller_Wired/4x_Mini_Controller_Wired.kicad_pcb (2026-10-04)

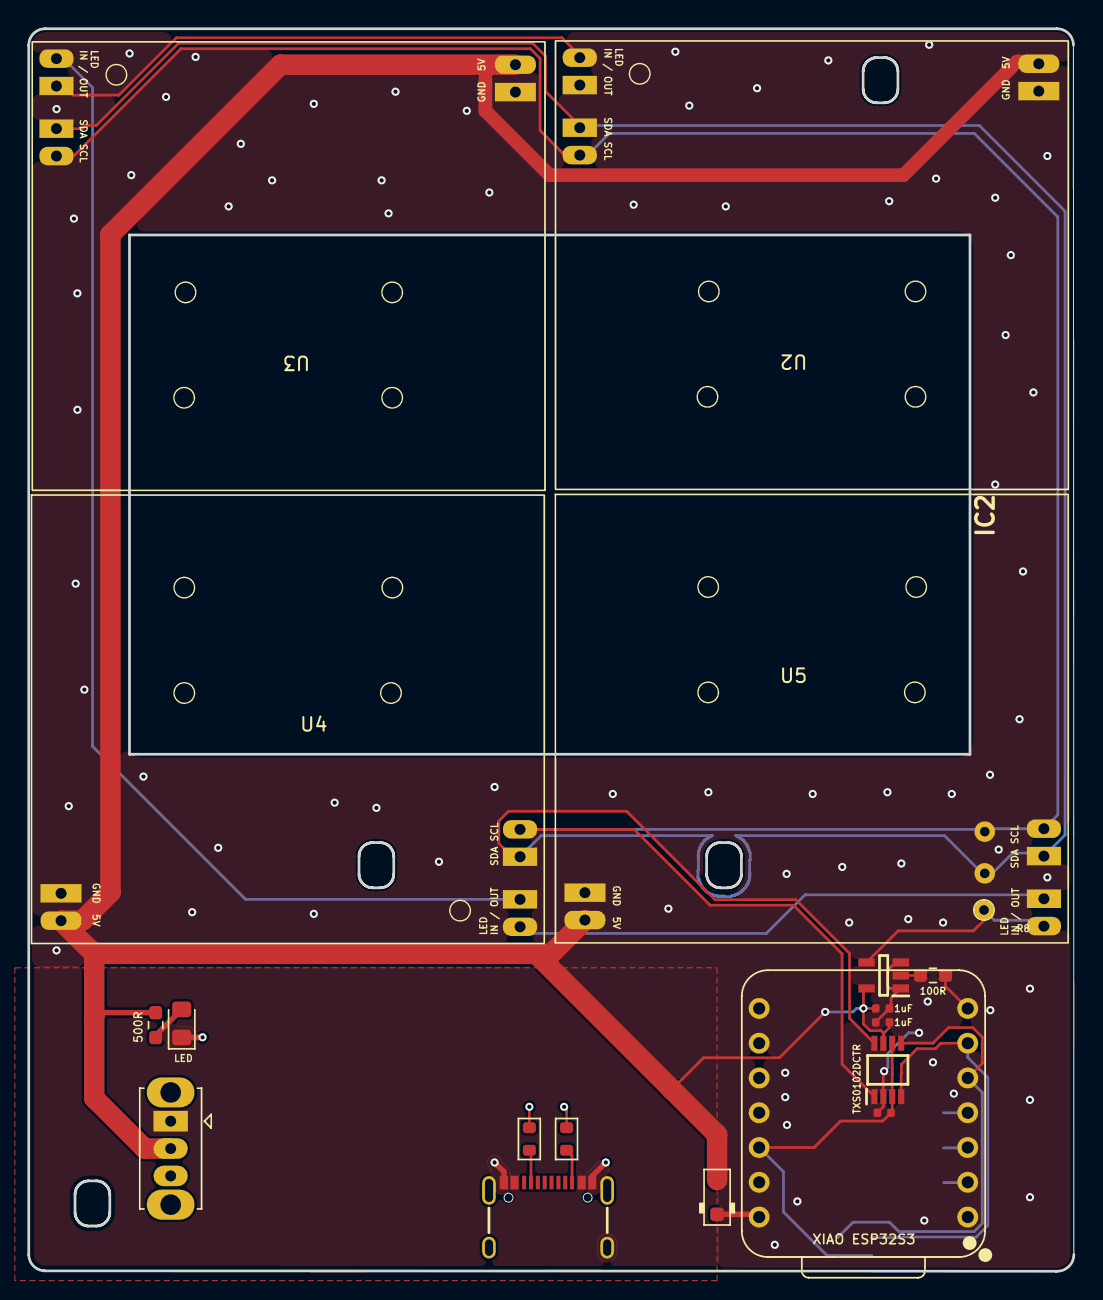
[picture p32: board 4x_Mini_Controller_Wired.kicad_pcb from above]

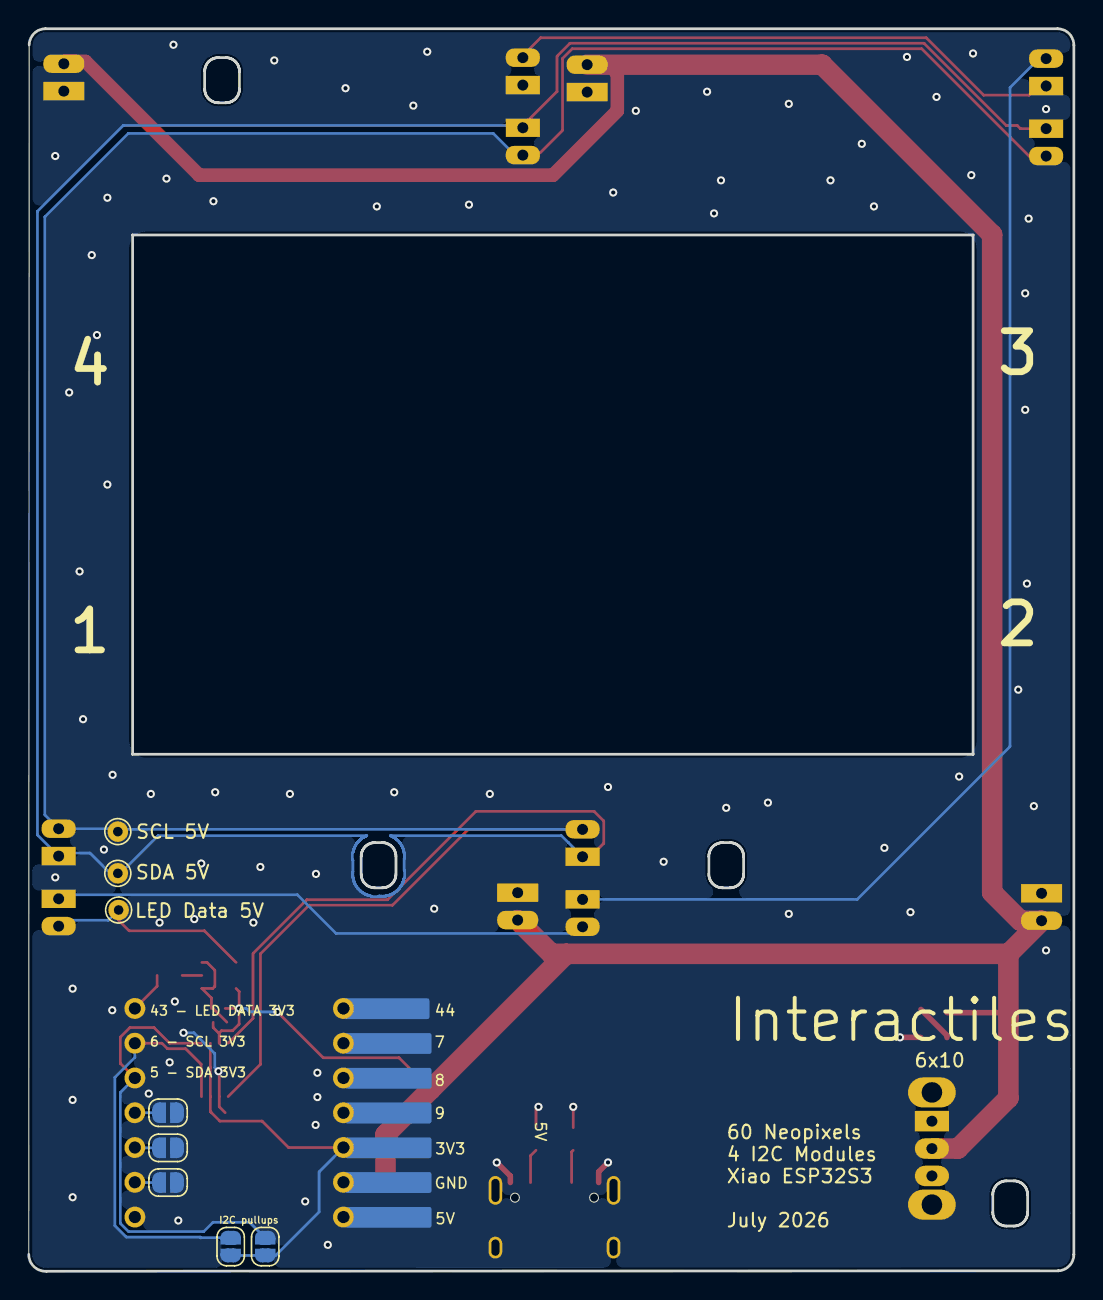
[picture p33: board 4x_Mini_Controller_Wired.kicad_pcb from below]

Board: 2 copper layers, 76.4 x 90.8 mm, 26 parts (8 on the bottom side), 21 nets.

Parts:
C2, C4, C7: 1uF; C_0402
D1: LED; LED_0805_2012Metric_Pad1.15x1.40mm_HandSolder
D6: 1N5817M; D_SOD-323_BigPads
IC2: TXS0102DCTR
IC3: SN74AHCT1G125DBVR
J2: USB_C_Receptacle; USB-C_16
JP1, JP2, JP5, JP6, JP7: SolderJumper_2_Open; SolderJumper-2_P1.3mm_Open_RoundedPad1.0x1.5mm
R1, R2: 5.1k; R_0603_1608Metric
R3: 500R; R_0603_1608Metric_Pad0.98x0.95mm_HandSolder
R8: 100R; R_0603_1608Metric_Pad0.98x0.95mm_HandSolder
SW5: Slide_Switch_SPDT; SW_Slide_SPDT_Straight_CK_OS102011MS2Q
TP3: SCL 5V; TestPoint_THTPad_D1.5mm_Drill0.7mm
TP4: SDA 5V; TestPoint_THTPad_D1.5mm_Drill0.7mm
TP5: LED Data 5V; TestPoint_THTPad_D1.5mm_Drill0.7mm
U2, U3, U4, U5: Mini_Module
U6: XIAO-ESP32-S3-SMD; XIAO-ESP32-S3-DIP

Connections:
+3V3: C4.1, IC2.3 (VCCA), IC2.6 (OE), JP6.2 (B), JP7.1 (A), U6.12 (3V3_OUT)
+5V: C2.1, C7.1, D6.2 (A), IC2.7 (VCCB), IC3.5 (VCC), R3.2, SW5.2, U2.5V, U3.5V, U4.5V, U5.5V
/5V to ESP32: D6.1 (K), U6.14 (VBUS)
/5V_TO_SWITCH: J2.VBUS, SW5.1
DATA_3v3: R8.1, U6.7 (D6)
DATA_5v: IC3.4 (Y), TP5.1 (1_1), U5.IN
DIP_1: JP1.1 (A), U6.2 (D1)
DIP_2: JP2.1 (A), U6.3 (D2)
DIP_3: JP5.1 (A), U6.4 (D3)
GND: C2.2, C4.2, C7.2, D1.1, IC2.2 (GND), IC3.1 (~OE), IC3.3 (GND), J2.GND, J2.S (SHIELD), JP1.2 (B), JP2.2 (B), JP5.2 (B), R1.2, R2.2, U2.GND, U3.GND, U4.GND, U5.GND, U6.13 (GND)
unnamed: D1.2, R3.1
unnamed: IC3.2 (A), R8.2
unnamed: J2.A5 (CC1), R1.1
unnamed: J2.B5 (CC2), R2.1
unnamed: U2.IN, U3.OUT
unnamed: U3.IN, U4.OUT
unnamed: U4.IN, U5.OUT
SCL_3v3: IC2.4 (A2), JP7.2 (B), U6.6 (D5)
SCL_5v: IC2.1 (B2), TP3.1 (1_1), U2.SCL, U3.SCL, U4.SCL, U5.SCL
SDA_3v3: IC2.5 (A1), JP6.1 (A), U6.5 (D4)
SDA_5v: IC2.8 (B1), TP4.1 (1_1), U2.SDA, U3.SDA, U4.SDA, U5.SDA

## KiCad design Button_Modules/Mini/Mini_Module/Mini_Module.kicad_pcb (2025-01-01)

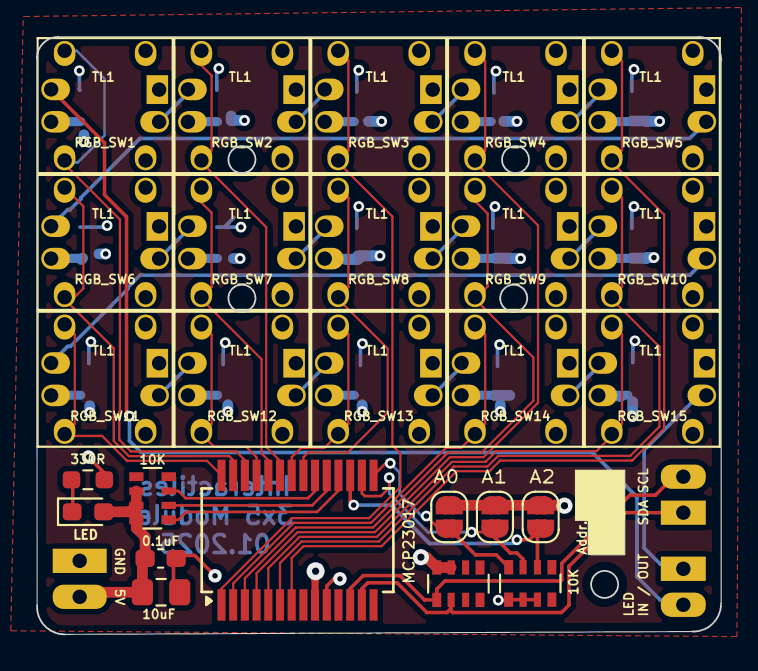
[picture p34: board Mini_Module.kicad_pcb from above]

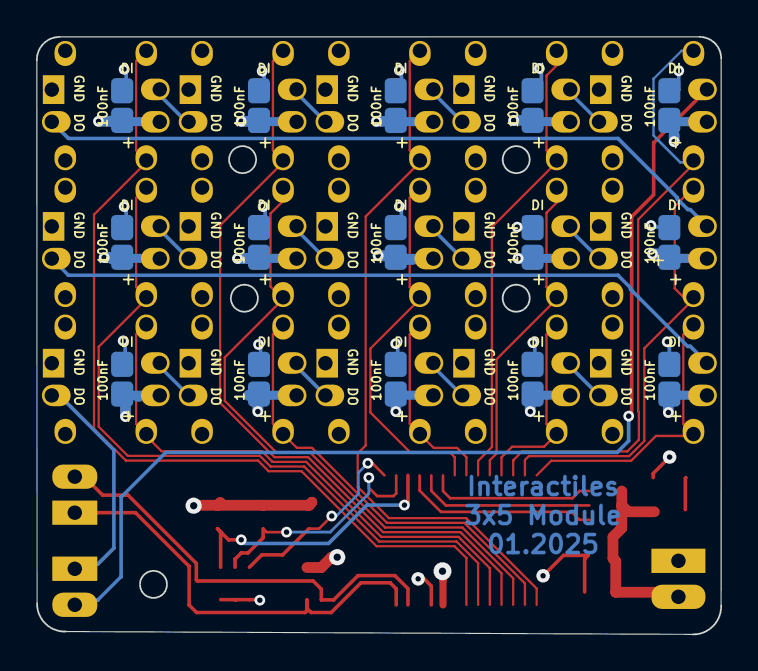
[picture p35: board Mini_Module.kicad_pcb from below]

Board: 4 copper layers, 38.0 x 33.2 mm, 29 parts (3 on the bottom side), 42 nets.

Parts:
0.1uF: 0.1uF; C_0603_1608Metric_Pad1.08x0.95mm_HandSolder
10uF: 10uF; C_0805_2012Metric_Pad1.18x1.45mm_HandSolder
J1: PINHD_1x2_Male; PinHeader_1x02_P2.00mm_Vertical
J2, J4: PINHD_1x2_Female; PinHeader_1x02_P2.00mm_Vertical
JP1, JP2, JP3: SolderJumper_2_Open; SolderJumper-2_P1.3mm_Open_RoundedPad1.0x1.5mm
LED: LED; LED_0603_1608Metric_Pad1.05x0.95mm_HandSolder
MCP23017: MCP23017_SS; SSOP-28_5.3x10.2mm_P0.65mm
R1: 330R; R_0603_1608Metric_Pad0.98x0.95mm_HandSolder
RGB_SW1, RGB_SW2, RGB_SW3, RGB_SW4, RGB_SW5, RGB_SW6, RGB_SW7, RGB_SW8, RGB_SW9, RGB_SW10, RGB_SW11, RGB_SW12, RGB_SW13, RGB_SW14, RGB_SW15: PLB_RGB_SW; TL1_RBG_Adressable_1_mini
RN1, RN2, RN3: R_Pack04; R_Array_Convex_4x0603

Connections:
+5V: 0.1uF.1, 10uF.1, J1.1, JP1.2 (B), JP2.2 (B), JP3.2 (B), LED.2, MCP23017.9 (VDD), RGB_SW1.VDD, RGB_SW2.VDD, RGB_SW3.VDD, RGB_SW4.VDD, RGB_SW5.VDD, RGB_SW6.VDD, RGB_SW7.VDD, RGB_SW8.VDD, RGB_SW9.VDD, RGB_SW10.VDD, RGB_SW11.VDD, RGB_SW12.VDD, RGB_SW13.VDD, RGB_SW14.VDD, RGB_SW15.VDD, RN2.6 (R3.2), RN2.7 (R2.2), RN2.8 (R1.2), RN3.7 (R2.2), RN3.8 (R1.2)
GND: 0.1uF.2, 10uF.2, J1.2, MCP23017.10 (VSS), R1.2, RGB_SW1.GND, RGB_SW1.SW2, RGB_SW2.GND, RGB_SW2.SW2, RGB_SW3.GND, RGB_SW3.SW2, RGB_SW4.GND, RGB_SW4.SW2, RGB_SW5.GND, RGB_SW5.SW2, RGB_SW6.GND, RGB_SW6.SW2, RGB_SW7.GND, RGB_SW7.SW2, RGB_SW8.GND, RGB_SW8.SW2, RGB_SW9.GND, RGB_SW9.SW2, RGB_SW10.GND, RGB_SW10.SW2, RGB_SW11.GND, RGB_SW11.SW2, RGB_SW12.GND, RGB_SW12.SW2, RGB_SW13.GND, RGB_SW13.SW2, RGB_SW14.GND, RGB_SW14.SW2, RGB_SW15.GND, RGB_SW15.SW2, RN1.1 (R1.1), RN1.2 (R2.1), RN1.3 (R3.1)
LED_IN: J2.1, RGB_SW1.DI (DIN)
LED_OUT: J2.2, RGB_SW15.DO
unnamed: LED.1, R1.1
unnamed: JP1.1 (A), MCP23017.15 (A0), RN1.8 (R1.2)
unnamed: JP2.1 (A), MCP23017.16 (A1), RN1.7 (R2.2)
unnamed: JP3.1 (A), MCP23017.17 (A2), RN1.6 (R3.2)
unnamed: RGB_SW1.DO, RGB_SW2.DI (DIN)
unnamed: RGB_SW2.DO, RGB_SW3.DI (DIN)
unnamed: RGB_SW3.DO, RGB_SW4.DI (DIN)
unnamed: RGB_SW4.DO, RGB_SW5.DI (DIN)
unnamed: RGB_SW5.DO, RGB_SW6.DI (DIN)
unnamed: RGB_SW6.DO, RGB_SW7.DI (DIN)
unnamed: RGB_SW7.DO, RGB_SW8.DI (DIN)
unnamed: RGB_SW8.DO, RGB_SW9.DI (DIN)
unnamed: RGB_SW9.DO, RGB_SW10.DI (DIN)
unnamed: RGB_SW10.DO, RGB_SW11.DI (DIN)
unnamed: RGB_SW11.DO, RGB_SW12.DI (DIN)
unnamed: RGB_SW12.DO, RGB_SW13.DI (DIN)
unnamed: RGB_SW13.DO, RGB_SW14.DI (DIN)
unnamed: RGB_SW14.DO, RGB_SW15.DI (DIN)
unnamed: MCP23017.18 (~RESET), RN2.1 (R1.1)
unnamed: MCP23017.19 (INTB), RN2.2 (R2.1)
unnamed: MCP23017.20 (INTA), RN2.3 (R3.1)
SCL: J4.1, MCP23017.12 (SCK), RN3.1 (R1.1)
SDA: J4.2, MCP23017.13 (SDA), RN3.2 (R2.1)
SW1: MCP23017.26 (GPA5), RGB_SW1.SW1
SW2: MCP23017.23 (GPA2), RGB_SW2.SW1
SW3: MCP23017.1 (GPB0), RGB_SW3.SW1
SW4: MCP23017.4 (GPB3), RGB_SW4.SW1
SW5: MCP23017.7 (GPB6), RGB_SW5.SW1
SW6: MCP23017.27 (GPA6), RGB_SW6.SW1
SW7: MCP23017.24 (GPA3), RGB_SW7.SW1
SW8: MCP23017.21 (GPA0), RGB_SW8.SW1
SW9: MCP23017.3 (GPB2), RGB_SW9.SW1
SW10: MCP23017.6 (GPB5), RGB_SW10.SW1
SW11: MCP23017.28 (GPA7), RGB_SW11.SW1
SW12: MCP23017.25 (GPA4), RGB_SW12.SW1
SW13: MCP23017.22 (GPA1), RGB_SW13.SW1
SW14: MCP23017.2 (GPB1), RGB_SW14.SW1
SW15: MCP23017.5 (GPB4), RGB_SW15.SW1

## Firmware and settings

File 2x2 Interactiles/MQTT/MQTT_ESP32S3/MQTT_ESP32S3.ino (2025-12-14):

//Identical code as MQTT_ESP32C3, but with different pin allocations
/* 

Current Issues:
  [] MQTT connectivity - connecting very inconsistently
  [] There are a few versions of the debug messages in the serial monitor?
Features to add: 
  [] Use LEDs to add a loading animation while connecting to wifi & MQTT
Misc:
  [] Document how to monitor MQTT publishings
  [] Document how to monitor via web page

HOW TO RUN:
  Connect arduino IDE
  Select device XIAO ESP32S3
  Upload speed 11520
  Monitor via an MQTT client at test.mosquitto.org, port 1883
  
/* 

#include <WiFi.h>
#include <PubSubClient.h>
#include <Adafruit_NeoPixel.h>
#include <Keypad.h>
#include <string.h> 

// Wi-Fi credentials
const char* ssid = "SSID";
const char* password = "PASSWORD";

#define PIN 44
#define NUMPIXELS 4

Adafruit_NeoPixel strip = Adafruit_NeoPixel(NUMPIXELS, PIN, NEO_RGB + NEO_KHZ800);

// MQTT setup
const char* mqtt_server = "test.mosquitto.org";
const int mqtt_port = 1883;
const char* base_topic = "interactiles/space1";

WiFiClient espClient;
PubSubClient client(espClient);

// Keypad setup
const byte ROWS = 2;
const byte COLS = 2;
char keys[ROWS][COLS] = {{'4','2'}, {'3','1'}};
byte rowPins[ROWS] = {43, 4};
byte colPins[COLS] = {8, 9};
Keypad keypad = Keypad(makeKeymap(keys), rowPins, colPins, ROWS, COLS);

const int numStates = 8;
enum LedState { OFF, RED, ORANGE, GREEN, TEAL, BLUE, PURPLE, WHITE }; 
LedState currentStates[NUMPIXELS] = {OFF, OFF, OFF, OFF};

void setup_wifi() {
  Serial.print("Connecting to WiFi");
  WiFi.begin(ssid, password);
  while (WiFi.status() != WL_CONNECTED) {
    delay(500);
    Serial.print(".");
  }
  Serial.println("\nConnected!");
  Serial.print("IP: ");
  Serial.println(WiFi.localIP());
}

void callback(char* topic, byte* payload, unsigned int length) {
  char msg[length + 1];
  memcpy(msg, payload, length);
  msg[length] = '\0';
  
  Serial.print("Received [");
  Serial.print(topic);
  Serial.print("]: ");
  Serial.println(msg);

  char topicCopy[50];
  strncpy(topicCopy, topic, sizeof(topicCopy));
  topicCopy[sizeof(topicCopy) - 1] = '\0';

  int row, col, r, g, b;
  if (sscanf(topicCopy, "interactiles/space1/%d/%d", &row, &col) == 2) {
    char* comma = strchr(msg, ',');
    if (comma) {
      *comma = ' ';
      char* comma2 = strchr(comma + 1, ',');
      if (comma2) *comma2 = ' ';
      
      if (sscanf(msg, "%d %d %d", &r, &g, &b) == 3) {
        int ledIndex = mapToLedIndex(row, col);
        if (ledIndex >= 0 && ledIndex < NUMPIXELS) {
          strip.setPixelColor(ledIndex, strip.Color(
            constrain(r, 0, 255),
            constrain(g, 0, 255),
            constrain(b, 0, 255)
          ));
          strip.show();
        }
      }
    }
  }
}

void reconnect() {
  while (!client.connected()) {
    Serial.print("Connecting to MQTT...");
    String clientId = "ESP32Client-2" + String(random(0xffff), HEX);
    if (client.connect(clientId.c_str())) {
      Serial.println("connected");
      client.subscribe("interactiles/space1/#");
    } else {
      Serial.print("failed, rc=");
      Serial.print(client.state());
      Serial.println(" retrying in 5s");
      delay(5000);
    }
  }
}

void setup() {
  Serial.begin(115200);
  strip.begin();
  strip.show();
  strip.setBrightness(80);
  setup_wifi();
  client.setServer(mqtt_server, mqtt_port);
  client.setCallback(callback);
  randomSeed(micros());
}

void loop() {
  if (!client.connected()) {
    reconnect();
  }
  client.loop();

  char key = keypad.getKey();
  if (key) {
    Serial.print("Key pressed: ");
    Serial.println(key);

    int ledIndex = -1;
    int row = -1, col = -1;

    switch (key) {
      case '1': ledIndex = 0; row = 1; col = 1; break;
      case '2': ledIndex = 2; row = 1; col = 2; break;
      case '3': ledIndex = 1; row = 2; col = 1; break;
      case '4': ledIndex = 3; row = 2; col = 2; break;
    }

    if (ledIndex != -1) {
      currentStates[ledIndex] = static_cast<LedState>((currentStates[ledIndex] + 1) % numStates);
      updateLed(ledIndex);

      uint32_t color = strip.getPixelColor(ledIndex);
      uint8_t r = (color >> 16) & 0xFF;
      uint8_t g = (color >> 8) & 0xFF;
      uint8_t b = color & 0xFF;

      char full_topic[50];
      snprintf(full_topic, sizeof(full_topic), "%s/%d/%d", base_topic, row, col);
      
      char payload[20];
      snprintf(payload, sizeof(payload), "%d,%d,%d", r, g, b);
      
      if (client.publish(full_topic, payload)) {
        Serial.print("Published to ");
        Serial.print(full_topic);
        Serial.print(": ");
        Serial.println(payload);
      } else {
        Serial.println("Publish failed!");
      }
    }
    delay(50);
  }
}

void updateLed(int ledIndex) {
  switch (currentStates[ledIndex]) {
    case OFF:    strip.setPixelColor(ledIndex, 0); break;
    case RED:    strip.setPixelColor(ledIndex, strip.Color(255, 0, 0)); break;
    case ORANGE: strip.setPixelColor(ledIndex, strip.Color(255, 100, 0)); break;
    case GREEN:  strip.setPixelColor(ledIndex, strip.Color(0, 255, 0)); break;
    case TEAL:   strip.setPixelColor(ledIndex, strip.Color(0, 128, 128)); break;
    case BLUE:   strip.setPixelColor(ledIndex, strip.Color(0, 0, 255)); break;
    case PURPLE: strip.setPixelColor(ledIndex, strip.Color(128, 0, 128)); break;
    case WHITE:  strip.setPixelColor(ledIndex, strip.Color(255, 255, 255)); break;
  }
  strip.show();
}

int mapToLedIndex(int row, int col) {
  if (row == 1 && col == 1) return 0;
  if (row == 1 && col == 2) return 2;
  if (row == 2 && col == 1) return 1;
  if (row == 2 && col == 2) return 3;
  return -1;
}

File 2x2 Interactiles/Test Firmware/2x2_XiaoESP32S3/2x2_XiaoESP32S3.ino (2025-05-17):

//Code for 2x2 PCB using the Xiao Seeeduino ESP32S3

#include <Adafruit_NeoPixel.h>
#include <Keypad.h>

#define PIN 44           // Pin connected to the NeoPixel data line
#define NUMPIXELS 4      // Total number of pixels in the strip

Adafruit_NeoPixel strip = Adafruit_NeoPixel(NUMPIXELS, PIN, NEO_RGB + NEO_KHZ800);

// Keypad setup
const byte ROWS = 2; // 2 rows
const byte COLS = 2; // 2 columns
char keys[ROWS][COLS] = {
  {'4', '2'},
  {'3', '1'},
};
byte rowPins[ROWS] = {43, 4}; // Connect to the row pinouts of the keypad
byte colPins[COLS] = {8, 9};  // Connect to the column pinouts of the keypad

Keypad keypad = Keypad(makeKeymap(keys), rowPins, colPins, ROWS, COLS);

const int numStates = 8;
enum LedState {
  OFF,
  RED,
  ORANGE,
  GREEN,
  TEAL,
  BLUE,
  PURPLE,
  WHITE
};

LedState currentStates[NUMPIXELS] = {OFF, OFF, OFF, OFF}; // Start with all LEDs off

void setup() {
  Serial.begin(115200);
  Serial.println("Setting up NeoPixel...");

  strip.begin();
  strip.show();          // Initialize all pixels to 'off'
  strip.setBrightness(80); // Set brightness to a moderate level

  Serial.println("Setup complete.");
}

void loop() {
  char key = keypad.getKey();
  if (key) {
    Serial.print("Key pressed: ");
    Serial.println(key);

    // Mapping keys to the correct LED index
    int ledIndex = -1;
    switch (key) {
      case '1': ledIndex = 0; break; // Key 1 -> LED 4 -> NeoPixel index 3
      case '2': ledIndex = 2; break; // Key 2 -> LED 3 -> NeoPixel index 2
      case '3': ledIndex = 1; break; // Key 3 -> LED 2 -> NeoPixel index 1
      case '4': ledIndex = 3; break; // Key 4 -> LED 1 -> NeoPixel index 0
    }

    if (ledIndex != -1) {
      Serial.print("Controlling LED at index: ");
      Serial.println(ledIndex);

      currentStates[ledIndex] = static_cast<LedState>((currentStates[ledIndex] + 1) % numStates);
      updateLed(ledIndex);
    } else {
      Serial.println("Invalid key detected.");
    }

    // Simple debounce delay
    delay(50);
  }
}

void updateLed(int ledIndex) {
  Serial.print("Updating LED ");
  Serial.print(ledIndex);
  Serial.print(" to state ");
  Serial.println(currentStates[ledIndex]);

  switch (currentStates[ledIndex]) {
    case OFF:
      strip.setPixelColor(ledIndex, strip.Color(0, 0, 0)); // Turn off
      break;
    case RED:
      strip.setPixelColor(ledIndex, strip.Color(255, 0, 0)); // Red
      break;
    case ORANGE:
      strip.setPixelColor(ledIndex, strip.Color(255, 165, 0)); // Orange
      break;
    case GREEN:
      strip.setPixelColor(ledIndex, strip.Color(0, 255, 0)); // Green
      break;
    case TEAL:
      strip.setPixelColor(ledIndex, strip.Color(0, 128, 128)); // Teal
      break;
    case BLUE:
      strip.setPixelColor(ledIndex, strip.Color(0, 0, 255)); // Blue
      break;
    case PURPLE:
      strip.setPixelColor(ledIndex, strip.Color(128, 0, 128)); // Purple
      break;
    case WHITE:
      strip.setPixelColor(ledIndex, strip.Color(255, 255, 255)); // White
      break;
  }

  strip.show(); // Update the strip after setting the color
}

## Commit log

2024-11-05 added large module files
    [Honyone RGB Shield.kicad_pcb, Honyone RGB Shield.kicad_sch, Honyone RGB Shield.step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]
2024-11-05 Added Controller Package
    [Neopixel_Controller.kicad_sch]
2024-11-17 updated IO expander to bigger MCP23017 footprint
    [Neopixel_ioexpander.kicad_pcb, Neopixel_ioexpander.kicad_sch]
2024-11-23 replaced picoblade connectors with THT pads, moved some stuff around
    [Interactiles_Module_Neopixel.kicad_pcb, Interactiles_Module_Neopixel.kicad_sch]
2024-11-27 fixed for pcb production
    [Interactiles_Module_Neopixel.kicad_pcb, Interactiles_Module_Neopixel.kicad_sch, Neopixel_ioexpander.kicad_pcb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]
2025-01-01 PCB Revisions
    MCP23017 had incorrect footprints, some tolerances between pads were too tight (shorts), resized some components
    [Interactiles_Module_Neopixel.kicad_pcb, Interactiles_Module_Neopixel.kicad_sch, Neopixel_ioexpander.kicad_pcb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]
2025-05-17 Fixed GRB to RGB 2x2_XiaoESP32C3.ino
    [2x2_XiaoESP32C3.ino]
2025-08-22 Added initial MQTT code
    [Neopixel_Controller.kicad_sch, Neopixel_Mini_Controller.kicad_sch, bom.csv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]
2025-12-14 Upload correct code
    added some to-dos. Debug connectivity issues
    [MQTT_ESP32S3.ino]
2026-07-07 Cleanup
    Cleaned up structure and naming, refreshed readmes, deleted or hid old useless files
    [4x_Mini_Controller.kicad_sch, 4x_Mini_Controller_Wired.kicad_sch, 4x_Mini_Controller_Wired.step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]
2026-07-07 Fix repo structure: move Interactiles content to root, remove MoodLogger
    MoodLogger now lives in its own repository (sullyjason/MoodLogger).
    Remove tracked .DS_Store and KiCad lock files, now covered by .gitignore.
    [4x_Mini_Controller.kicad_sch, 4x_Mini_Controller_Wired.kicad_sch, 4x_Mini_Controller_Wired.step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]
2026-10-04 relinked 3d files
    [4x_Mini_Controller_Wired.kicad_pcb, 4x_Mini_Controller_Wired.step, Interactiles_Controller.step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]
2026-10-04 Document build for Zürich Decompression 2026
    Add a "What we're building" section covering the boards used (the
    existing Interactiles Controller and two Large Modules), the USB-C
    power setup, and open technical risks.
